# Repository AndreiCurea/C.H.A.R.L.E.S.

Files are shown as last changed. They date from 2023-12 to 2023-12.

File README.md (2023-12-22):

# C.H.A.R.L.E.S.
Combustion Hazzard Autonomous Robot for Localization and Environmental Scanning

A hobby project of mine that involves building up an exploration robot from scratch, using different types of technologies. The purpose of this project is to monitor VOCs and other harmful gases in office/industrial buildings, while also creating a map of the surroundings to plot the acquired data on it.

I desired it to have LiDAR, ROS implementation, main computer board and high modularity when it comes to the electrical/mechanical parts.

It has custom PCBs, custom 3D parts, and code for the microcontrollers and the main computer.

Currently, the project only works remote controlled, as I've yet to develop the automation part of the code.

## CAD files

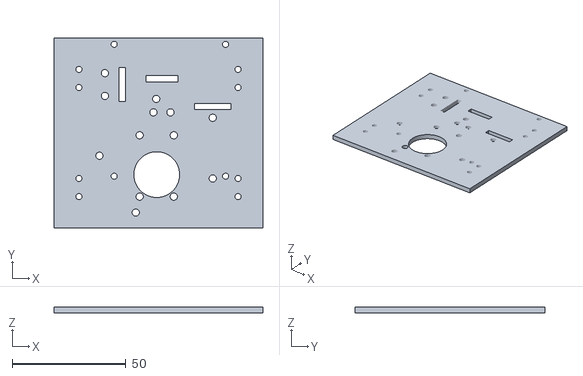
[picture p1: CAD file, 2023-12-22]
3D Designs/Assembly Bottom Layer v21.stl
91.9 x 83.6 x 2.50

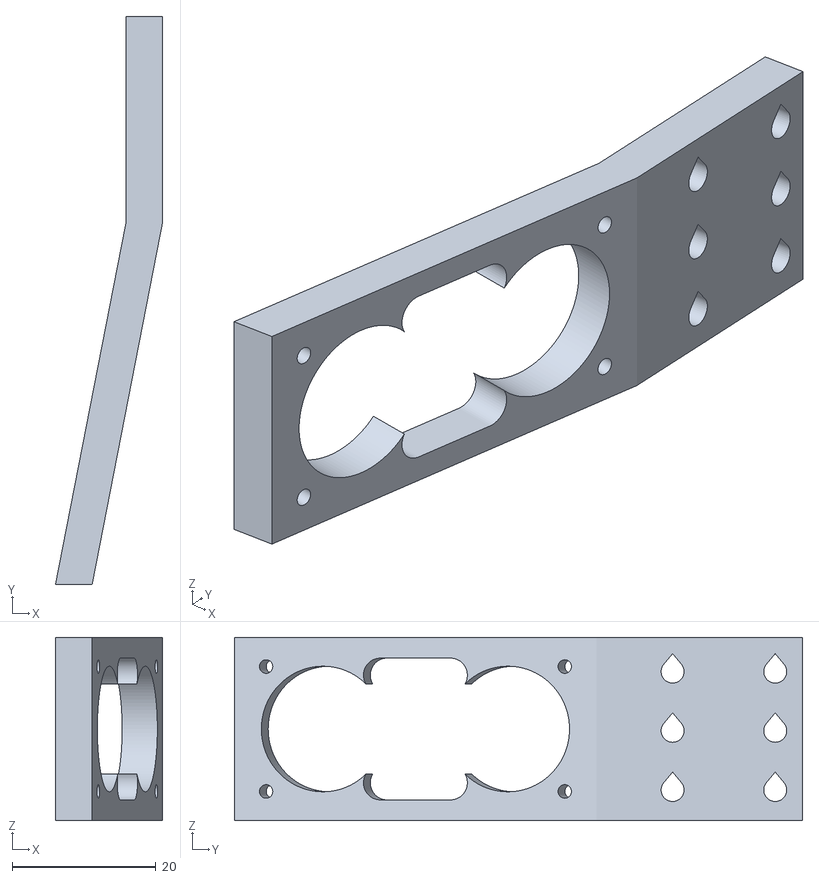
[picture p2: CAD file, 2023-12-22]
3D Designs/Aripa_Dreapta.stl
14.9 x 79.2 x 25.5

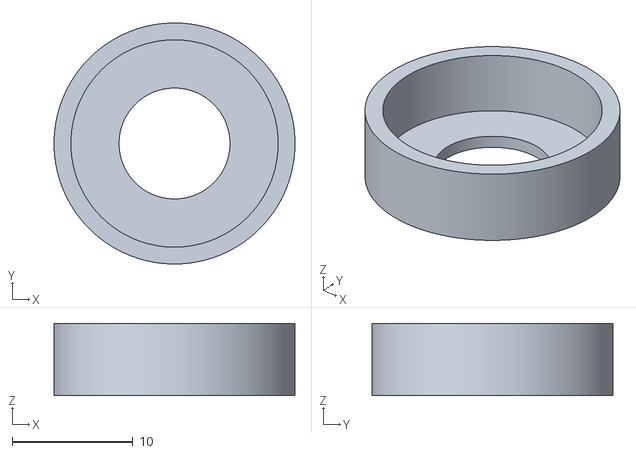
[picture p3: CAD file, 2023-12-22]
3D Designs/Test insert Motor.stl
20.0 x 20.0 x 6.00

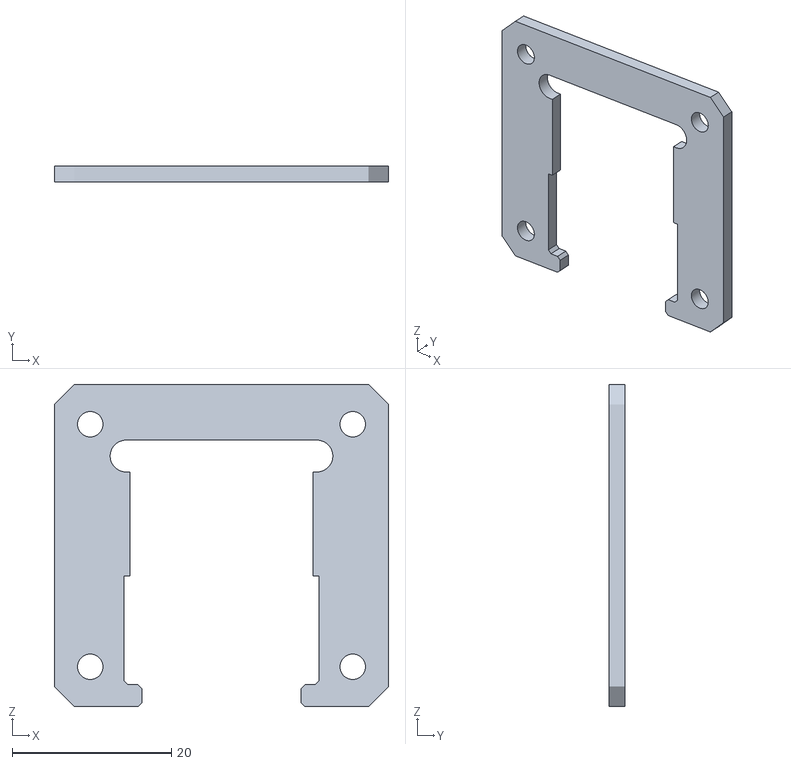
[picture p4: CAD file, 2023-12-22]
3D Designs/Capac_Battery_Level.stl
42.0 x 2.00 x 40.5

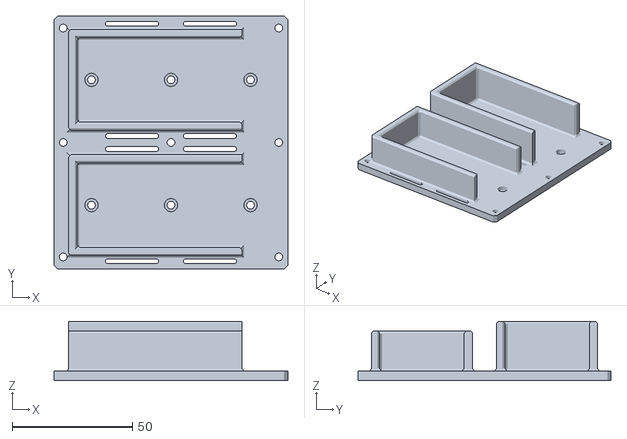
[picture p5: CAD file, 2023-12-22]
3D Designs/Suport_Baterii.stl
97.0 x 105.0 x 24.5

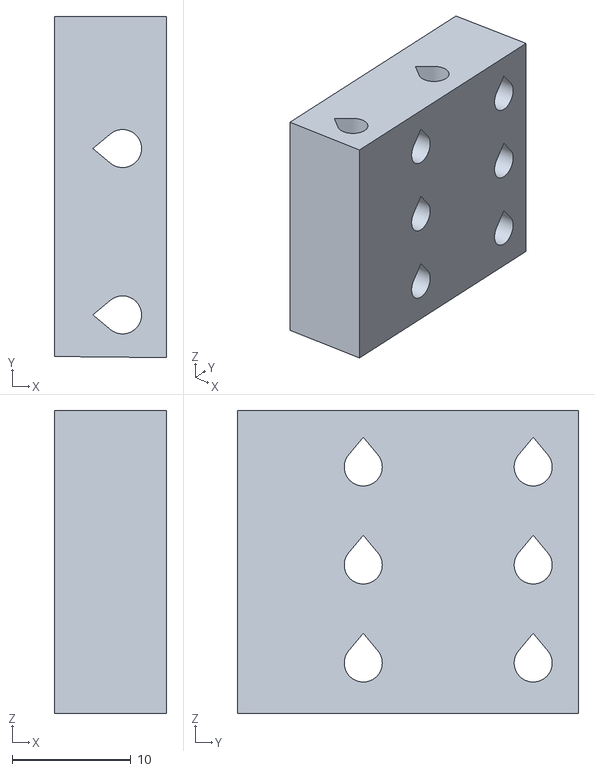
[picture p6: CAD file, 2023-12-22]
3D Designs/Bloc_Suport_Aripa_Dreapta.stl
9.44 x 28.7 x 25.5

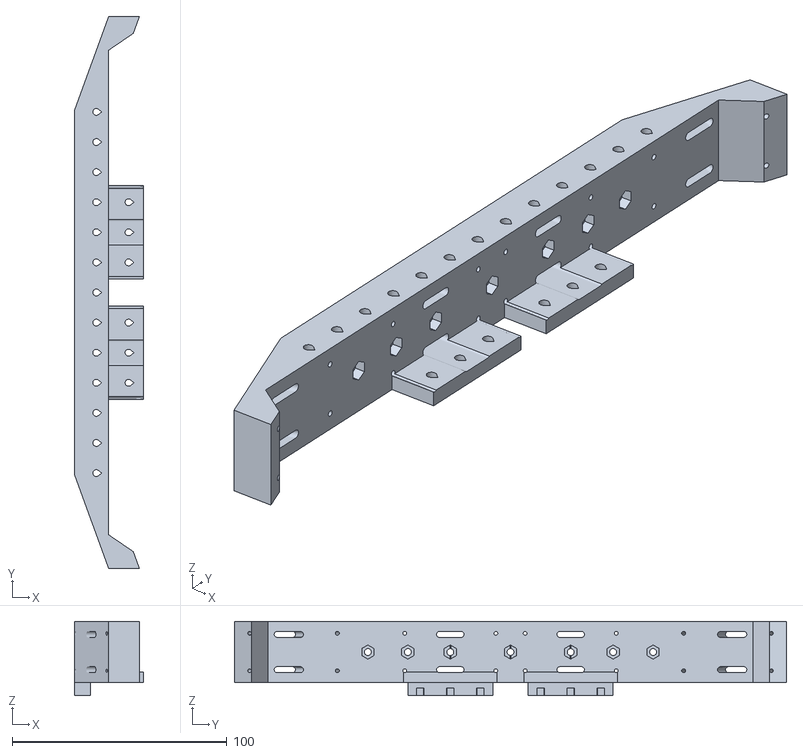
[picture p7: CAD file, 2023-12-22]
3D Designs/HC_SR04_Adapter.stl
32.0 x 256.8 x 34.5

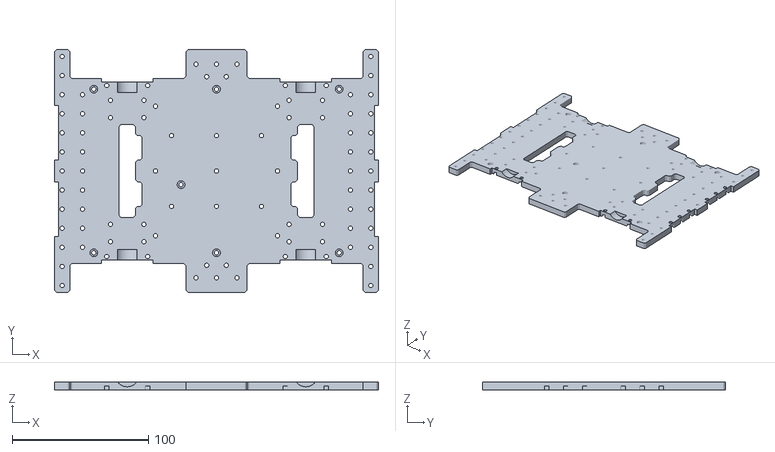
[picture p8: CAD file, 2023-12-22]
3D Designs/Bottom Layer 1.stl
237.7 x 178.0 x 6.00

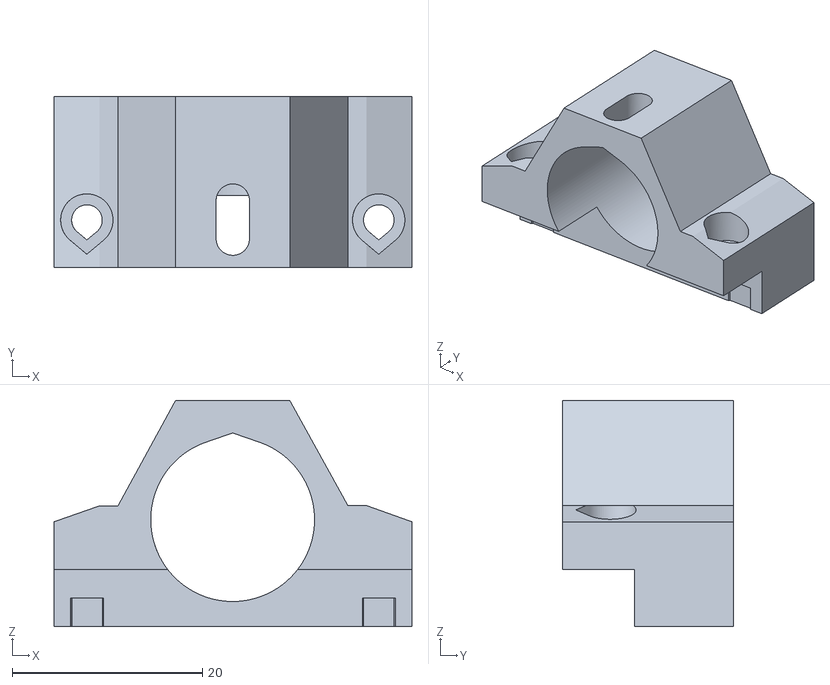
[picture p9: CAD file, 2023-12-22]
3D Designs/Suport_Rulment_Roata.stl
37.6 x 18.0 x 23.7

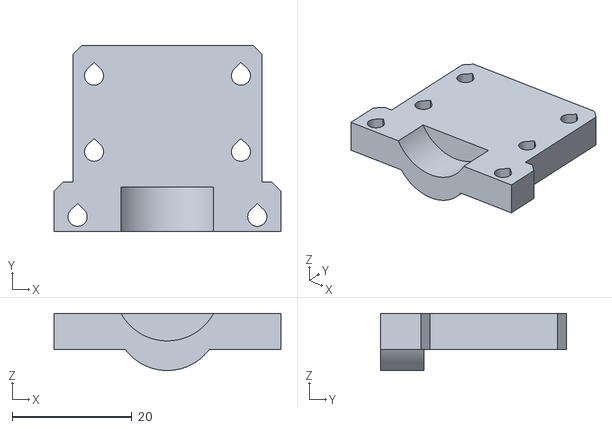
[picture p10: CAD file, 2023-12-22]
3D Designs/Inaltator_Roti.stl
37.9 x 31.1 x 9.52

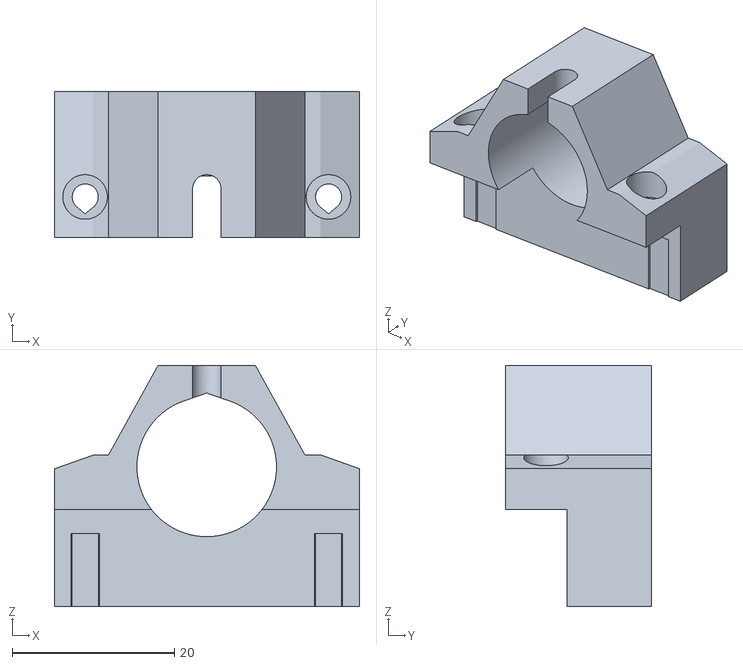
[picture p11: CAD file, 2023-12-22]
3D Designs/Suport_Rulment_Roata_plusInaltator.stl
37.6 x 18.0 x 29.7

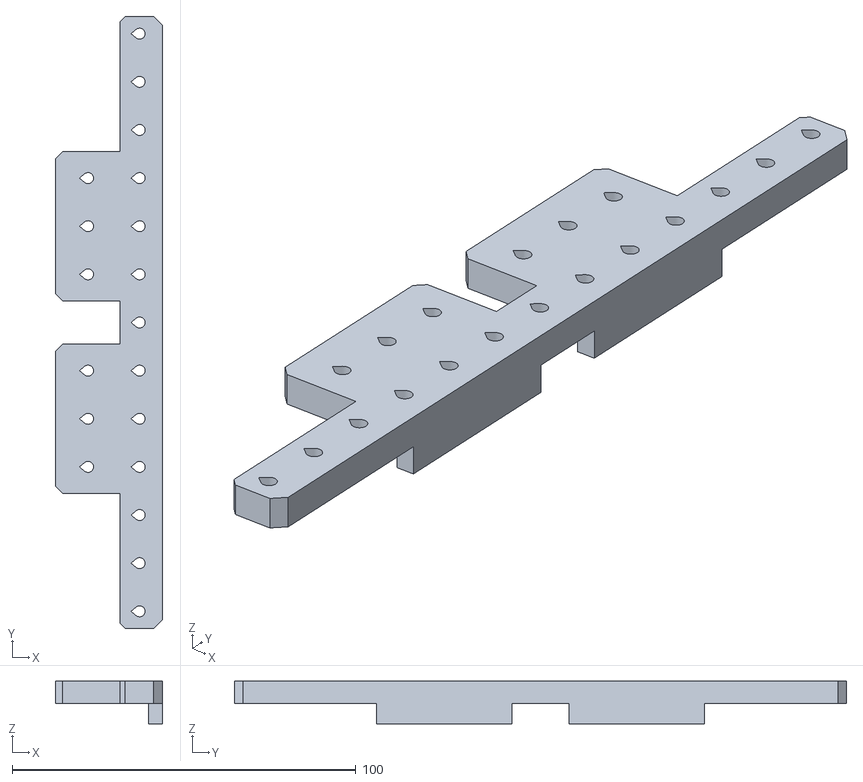
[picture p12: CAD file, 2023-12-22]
3D Designs/Base_Support_Ultrasonic.stl
31.0 x 178.0 x 12.5

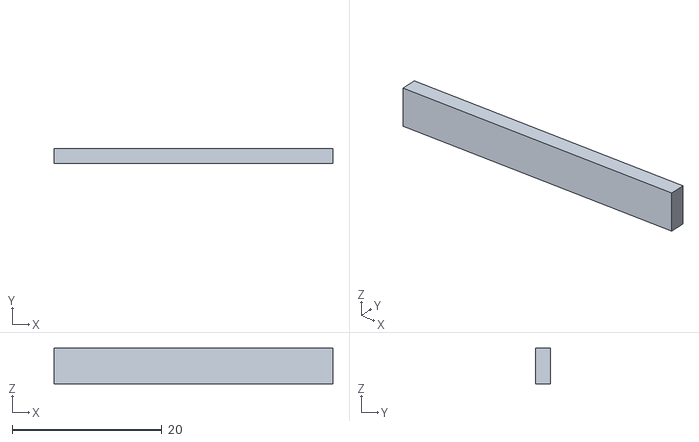
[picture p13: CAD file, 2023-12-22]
3D Designs/test insert MotM.stl
37.2 x 2.00 x 4.80

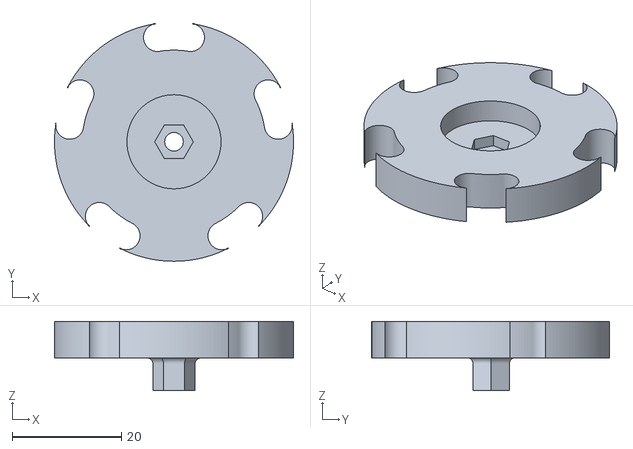
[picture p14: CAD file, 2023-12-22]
3D Designs/Suport_Roata.stl
43.7 x 43.4 x 12.7

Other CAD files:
3D Designs/Bottom Layer 1_Holes.stl
3D Designs/Aripa_Stanga.stl
3D Designs/Bloc_Suport_Aripa_Stanga.stl
3D Designs/Suport Motor.stl
3D Designs/Batt_ Conn_Dreapta.stl
3D Designs/Batt_ Conn_Stanga.stl
3D Designs/Clips_Cuplaj_Mecanic.stl
3D Designs/Front_Support_Ultrasonic.stl
3D Designs/Middle_Layer_2.stl
3D Designs/Separator Rulment.stl
3D Designs/Separator_Rulment.stl
3D Designs/Suport Separator Rulment.stl
3D Designs/Suport_Battery_Level.stl
3D Designs/TOP_Layer_3.stl
3D Designs/Test_HCSR04.stl
3D Designs/Test_Hole_Mot_Mount.stl
3D Designs/Test_Ins_Mot_Mount.stl
3D Designs/Ziptie_Holder.stl
3D Designs/test_Gauri.stl

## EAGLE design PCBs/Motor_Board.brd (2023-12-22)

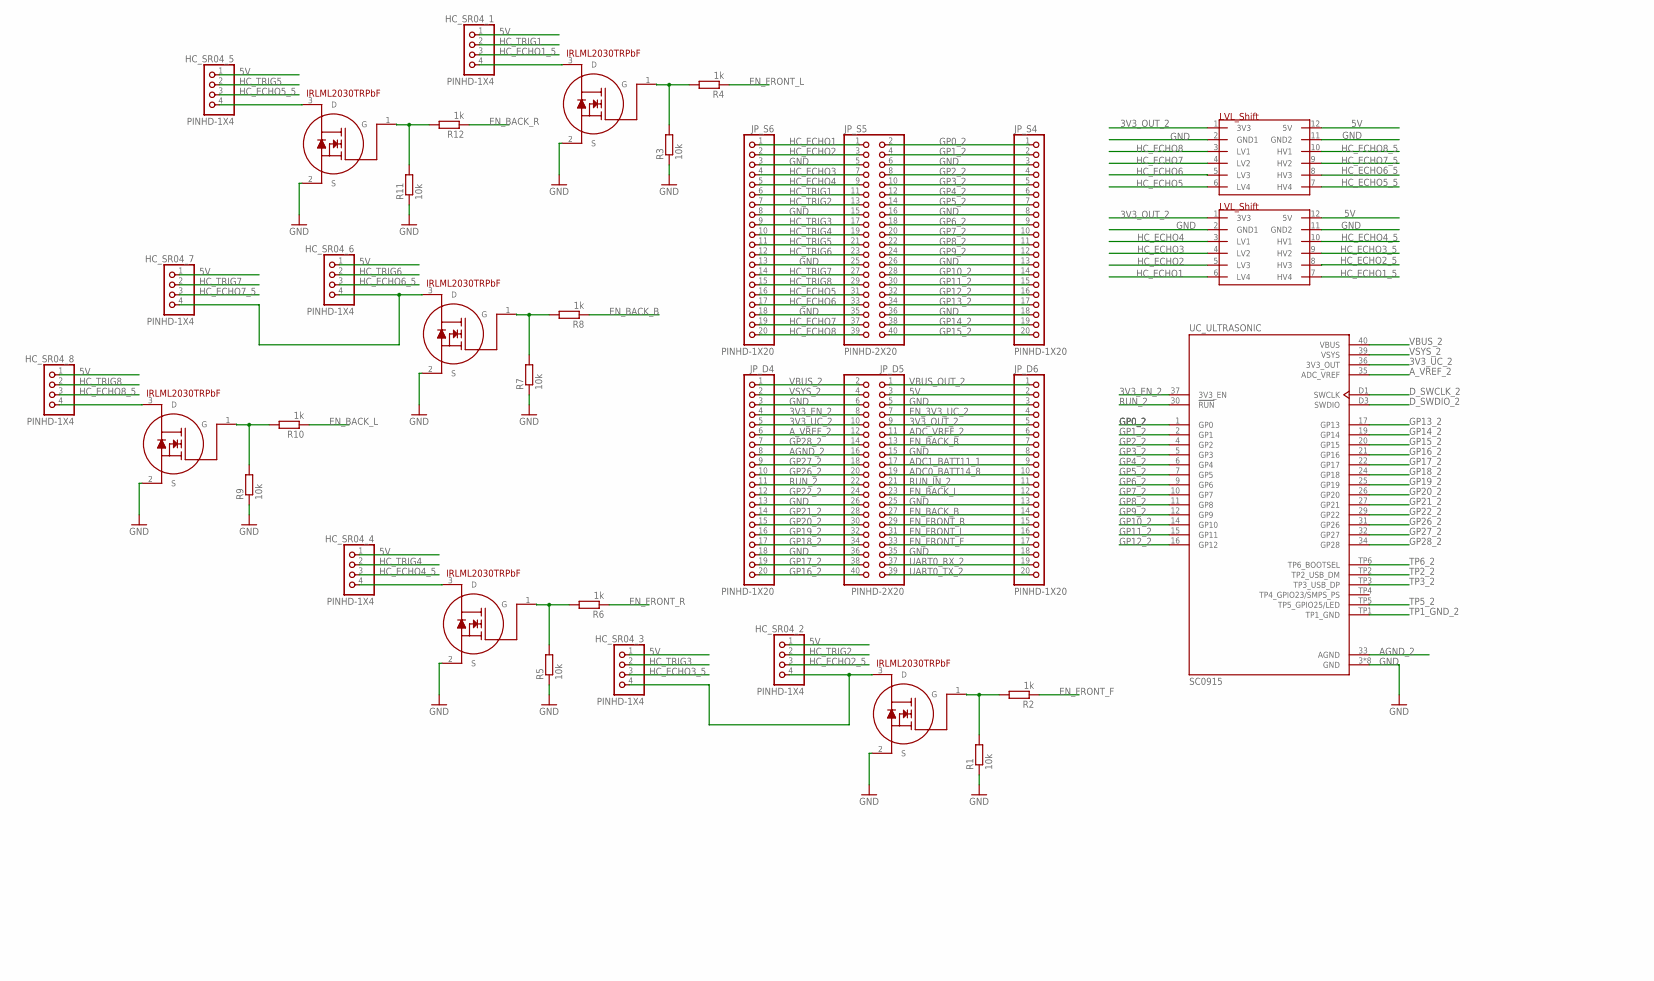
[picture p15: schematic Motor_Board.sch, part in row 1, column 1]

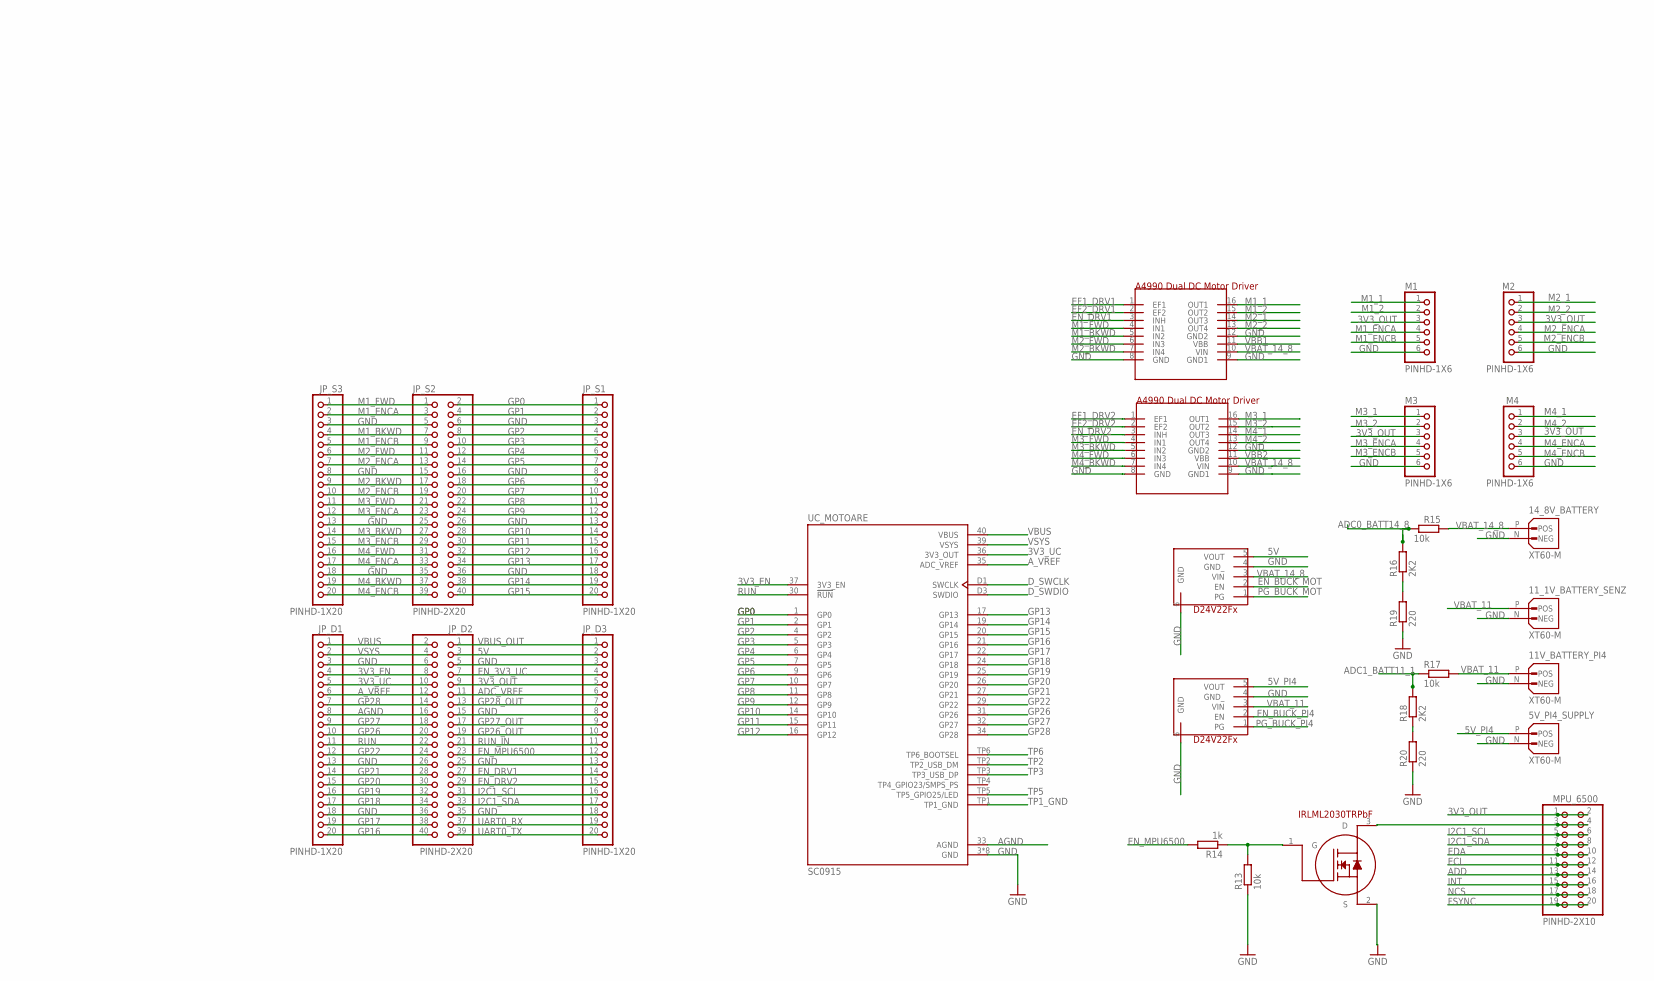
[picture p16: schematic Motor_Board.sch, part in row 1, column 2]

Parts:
5V_PI4_SUPPLY, 11V_BATTERY_PI4, 11_1V_BATTERY_SENZ, 14_8V_BATTERY: XT60-M; AMASS_XT60-M
BUCK_5V, BUCK_5V1: POLOLU_BUCK_CONVERTER; POLOLU_BUCK_FOOTPRINT
DRV1, DRV2: A4990_DUAL; A4990_FOOTPRINT
HC_SR04_1, HC_SR04_2, HC_SR04_3, HC_SR04_4, HC_SR04_5, HC_SR04_6, HC_SR04_7, HC_SR04_8: PINHD-1X4; 1X04
JP_D1, JP_D3, JP_D4, JP_D6: PINHD-1X20; 1X20
JP_D2, JP_D5: PINHD-2X20; 2X20
JP_S1, JP_S3, JP_S4, JP_S6: PINHD-1X20; 1X20
JP_S2, JP_S5: PINHD-2X20; 2X20
M1, M2, M3, M4: PINHD-1X6; 1X06
MPU_6500: PINHD-2X10; 2X10
R1, R3, R5, R7, R9, R11, R13, R15, R17: 10k; R0805
R2, R4, R6, R8, R10, R12, R14: 1k; R0805
R16, R18: 2K2; R0805
R19, R20: 220; R0805
U$1, U$2: 4_CH_BIDIRECTIONAL_LVL_SHIFTER; LVL_SHIFT_FOOTPRINT
U$8, U$9, U$10, U$11, U$12, U$13, U$14: IRLML2030TRBRBF_NMOS; IRLML2030TRPBF_FOOTPRINT
UC_MOTOARE: SC0915; MODULE_SC0915
UC_ULTRASONIC: SC0915; MODULE_SC0915

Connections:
3V3_EN: JP_D1.4, JP_D2.8, UC_MOTOARE.37 (3V3_EN)
3V3_EN_2: JP_D4.4, JP_D5.8, UC_ULTRASONIC.37 (3V3_EN)
3V3_OUT: JP_D2.9, JP_D3.5, M1.3, M2.3, M3.3, M4.3, MPU_6500.1, MPU_6500.2
3V3_OUT_2: JP_D5.9, JP_D6.5, U$1.1 (3V3), U$2.1 (3V3)
3V3_UC: JP_D1.5, JP_D2.10, UC_MOTOARE.36 (3V3_OUT)
3V3_UC_2: JP_D4.5, JP_D5.10, UC_ULTRASONIC.36 (3V3_OUT)
5V: BUCK_5V.5 (VOUT), HC_SR04_1.1, HC_SR04_2.1, HC_SR04_3.1, HC_SR04_4.1, HC_SR04_5.1, HC_SR04_6.1, HC_SR04_7.1, HC_SR04_8.1, JP_D2.3, JP_D3.2, JP_D5.3, JP_D6.2, U$1.12 (5V), U$2.12 (5V)
5V_PI4: 5V_PI4_SUPPLY.P (POS), BUCK_5V1.5 (VOUT)
ADC0_BATT14_8: JP_D5.19, JP_D6.10, R15.1, R16.2
ADC1_BATT11_1: JP_D5.17, JP_D6.9, R17.1, R18.2
ADC_VREF: JP_D2.11, JP_D3.6
ADC_VREF_2: JP_D5.11, JP_D6.6
ADD: MPU_6500.13, MPU_6500.14
AGND: JP_D1.8, JP_D2.16, UC_MOTOARE.33 (AGND)
AGND_2: JP_D4.8, JP_D5.16, UC_ULTRASONIC.33 (AGND)
A_VREF: JP_D1.6, JP_D2.12, UC_MOTOARE.35 (ADC_VREF)
A_VREF_2: JP_D4.6, JP_D5.12, UC_ULTRASONIC.35 (ADC_VREF)
D_SWCLK: UC_MOTOARE.D1 (SWCLK)
D_SWCLK_2: UC_ULTRASONIC.D1 (SWCLK)
D_SWDIO: UC_MOTOARE.D3 (SWDIO)
D_SWDIO_2: UC_ULTRASONIC.D3 (SWDIO)
ECL: MPU_6500.11, MPU_6500.12
EDA: MPU_6500.9, MPU_6500.10
EF1_DRV1: DRV1.1 (EF1)
EF1_DRV2: DRV2.1 (EF1)
EF2_DRV1: DRV1.2 (EF2)
EF2_DRV2: DRV2.2 (EF2)
EN_3V3_UC: JP_D2.7, JP_D3.4
EN_3V3_UC_2: JP_D5.7, JP_D6.4
EN_BACK_B: JP_D5.27, JP_D6.14, R8.1
EN_BACK_L: JP_D5.23, JP_D6.12, R10.1
EN_BACK_R: JP_D5.13, JP_D6.7, R12.1
EN_BUCK_MOT: BUCK_5V.2 (EN)
EN_BUCK_PI4: BUCK_5V1.2 (EN)
EN_DRV1: DRV1.3 (INH), JP_D2.27, JP_D3.14
EN_DRV2: DRV2.3 (INH), JP_D2.29, JP_D3.15
EN_FRONT_F: JP_D5.33, JP_D6.17, R2.1
EN_FRONT_L: JP_D5.31, JP_D6.16, R4.1
EN_FRONT_R: JP_D5.29, JP_D6.15, R6.1
EN_MPU6500: JP_D2.23, JP_D3.12, R14.2
FSYNC: MPU_6500.19, MPU_6500.20
GND: 5V_PI4_SUPPLY.N (NEG), 11V_BATTERY_PI4.N (NEG), 11_1V_BATTERY_SENZ.N (NEG), 14_8V_BATTERY.N (NEG), BUCK_5V.4 (GND_), BUCK_5V.6 (GND), BUCK_5V1.4 (GND_), BUCK_5V1.6 (GND), DRV1.8 (GND), DRV1.9 (GND1), DRV1.12 (GND2), DRV2.8 (GND), DRV2.9 (GND1), DRV2.12 (GND2), JP_D1.3, JP_D1.13, JP_D1.18, JP_D2.5, JP_D2.6, JP_D2.15, JP_D2.25, JP_D2.26, JP_D2.35, JP_D2.36, JP_D3.3, JP_D3.8, JP_D3.13, JP_D3.18, JP_D4.3, JP_D4.13, JP_D4.18, JP_D5.5, JP_D5.6, JP_D5.15, JP_D5.25, JP_D5.26, JP_D5.35, JP_D5.36, JP_D6.3, JP_D6.8, JP_D6.13, JP_D6.18, JP_S1.3, JP_S1.8, JP_S1.13, JP_S1.18, JP_S2.5, JP_S2.6, JP_S2.15, JP_S2.16, JP_S2.25, JP_S2.26, JP_S2.35, JP_S2.36, JP_S3.3, JP_S3.8, JP_S3.13, JP_S3.18, JP_S4.3, JP_S4.8, JP_S4.13, JP_S4.18, JP_S5.5, JP_S5.6, JP_S5.15, JP_S5.16, JP_S5.25, JP_S5.26, JP_S5.35, JP_S5.36, JP_S6.3, JP_S6.8, JP_S6.13, JP_S6.18, M1.6, M2.6, M3.6, M4.6, R1.1, R3.1, R5.1, R7.1, R9.1, R11.1, R13.1, R19.1, R20.1, U$1.2 (GND1), U$1.11 (GND2), U$2.2 (GND1), U$2.11 (GND2), U$8.2 (S), U$9.2 (S), U$10.2 (S), U$11.2 (S), U$12.2 (S), U$13.2 (S), U$14.2 (S), UC_MOTOARE.3 (GND), UC_MOTOARE.8 (GND), UC_MOTOARE.13 (GND), UC_MOTOARE.18 (GND), UC_MOTOARE.23 (GND), UC_MOTOARE.28 (GND), UC_MOTOARE.38 (GND), UC_MOTOARE.D2 (GND), UC_ULTRASONIC.3 (GND), UC_ULTRASONIC.8 (GND), UC_ULTRASONIC.13 (GND), UC_ULTRASONIC.18 (GND)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
GP0: JP_S1.1, JP_S2.2, UC_MOTOARE.1 (GP0)
GP0_2: JP_S4.1, JP_S5.2, UC_ULTRASONIC.1 (GP0)
GP1: JP_S1.2, JP_S2.4, UC_MOTOARE.2 (GP1)
GP1_2: JP_S4.2, JP_S5.4, UC_ULTRASONIC.2 (GP1)
GP2: JP_S1.4, JP_S2.8, UC_MOTOARE.4 (GP2)
GP2_2: JP_S4.4, JP_S5.8, UC_ULTRASONIC.4 (GP2)
GP3: JP_S1.5, JP_S2.10, UC_MOTOARE.5 (GP3)
GP3_2: JP_S4.5, JP_S5.10, UC_ULTRASONIC.5 (GP3)
GP4: JP_S1.6, JP_S2.12, UC_MOTOARE.6 (GP4)
GP4_2: JP_S4.6, JP_S5.12, UC_ULTRASONIC.6 (GP4)
GP5: JP_S1.7, JP_S2.14, UC_MOTOARE.7 (GP5)
GP5_2: JP_S4.7, JP_S5.14, UC_ULTRASONIC.7 (GP5)
GP6: JP_S1.9, JP_S2.18, UC_MOTOARE.9 (GP6)
GP6_2: JP_S4.9, JP_S5.18, UC_ULTRASONIC.9 (GP6)
GP7: JP_S1.10, JP_S2.20, UC_MOTOARE.10 (GP7)
GP7_2: JP_S4.10, JP_S5.20, UC_ULTRASONIC.10 (GP7)
GP8: JP_S1.11, JP_S2.22, UC_MOTOARE.11 (GP8)
GP8_2: JP_S4.11, JP_S5.22, UC_ULTRASONIC.11 (GP8)
GP9: JP_S1.12, JP_S2.24, UC_MOTOARE.12 (GP9)
GP9_2: JP_S4.12, JP_S5.24, UC_ULTRASONIC.12 (GP9)
GP10: JP_S1.14, JP_S2.28, UC_MOTOARE.14 (GP10)
GP10_2: JP_S4.14, JP_S5.28, UC_ULTRASONIC.14 (GP10)
GP11: JP_S1.15, JP_S2.30, UC_MOTOARE.15 (GP11)
GP11_2: JP_S4.15, JP_S5.30, UC_ULTRASONIC.15 (GP11)
GP12: JP_S1.16, JP_S2.32, UC_MOTOARE.16 (GP12)
GP12_2: JP_S4.16, JP_S5.32, UC_ULTRASONIC.16 (GP12)
GP13: JP_S1.17, JP_S2.34, UC_MOTOARE.17 (GP13)
GP13_2: JP_S4.17, JP_S5.34, UC_ULTRASONIC.17 (GP13)
GP14: JP_S1.19, JP_S2.38, UC_MOTOARE.19 (GP14)
GP14_2: JP_S4.19, JP_S5.38, UC_ULTRASONIC.19 (GP14)
GP15: JP_S1.20, JP_S2.40, UC_MOTOARE.20 (GP15)
GP15_2: JP_S4.20, JP_S5.40, UC_ULTRASONIC.20 (GP15)
GP16: JP_D1.20, JP_D2.40, UC_MOTOARE.21 (GP16)
GP16_2: JP_D4.20, JP_D5.40, UC_ULTRASONIC.21 (GP16)
GP17: JP_D1.19, JP_D2.38, UC_MOTOARE.22 (GP17)
GP17_2: JP_D4.19, JP_D5.38, UC_ULTRASONIC.22 (GP17)
GP18: JP_D1.17, JP_D2.34, UC_MOTOARE.24 (GP18)
GP18_2: JP_D4.17, JP_D5.34, UC_ULTRASONIC.24 (GP18)
GP19: JP_D1.16, JP_D2.32, UC_MOTOARE.25 (GP19)
GP19_2: JP_D4.16, JP_D5.32, UC_ULTRASONIC.25 (GP19)
GP20: JP_D1.15, JP_D2.30, UC_MOTOARE.26 (GP20)
GP20_2: JP_D4.15, JP_D5.30, UC_ULTRASONIC.26 (GP20)
GP21: JP_D1.14, JP_D2.28, UC_MOTOARE.27 (GP21)
GP21_2: JP_D4.14, JP_D5.28, UC_ULTRASONIC.27 (GP21)
GP22: JP_D1.12, JP_D2.24, UC_MOTOARE.29 (GP22)
GP22_2: JP_D4.12, JP_D5.24, UC_ULTRASONIC.29 (GP22)
GP26: JP_D1.10, JP_D2.20, UC_MOTOARE.31 (GP26)
GP26_2: JP_D4.10, JP_D5.20, UC_ULTRASONIC.31 (GP26)
GP26_OUT: JP_D2.19, JP_D3.10
GP27: JP_D1.9, JP_D2.18, UC_MOTOARE.32 (GP27)
GP27_2: JP_D4.9, JP_D5.18, UC_ULTRASONIC.32 (GP27)
GP27_OUT: JP_D2.17, JP_D3.9
GP28: JP_D1.7, JP_D2.14, UC_MOTOARE.34 (GP28)
GP28_2: JP_D4.7, JP_D5.14, UC_ULTRASONIC.34 (GP28)
GP28_OUT: JP_D2.13, JP_D3.7
HC_ECHO1: JP_S5.1, JP_S6.1, U$2.6 (LV4)
HC_ECHO1_5: HC_SR04_1.3, U$2.7 (HV4)
HC_ECHO2: JP_S5.3, JP_S6.2, U$2.5 (LV3)
HC_ECHO2_5: HC_SR04_2.3, U$2.8 (HV3)
HC_ECHO3: JP_S5.7, JP_S6.4, U$2.4 (LV2)
HC_ECHO3_5: HC_SR04_3.3, U$2.9 (HV2)
HC_ECHO4: JP_S5.9, JP_S6.5, U$2.3 (LV1)
HC_ECHO4_5: HC_SR04_4.3, U$2.10 (HV1)
HC_ECHO5: JP_S5.31, JP_S6.16, U$1.6 (LV4)
HC_ECHO5_5: HC_SR04_5.3, U$1.7 (HV4)
HC_ECHO6: JP_S5.33, JP_S6.17, U$1.5 (LV3)
HC_ECHO6_5: HC_SR04_6.3, U$1.8 (HV3)
HC_ECHO7: JP_S5.37, JP_S6.19, U$1.4 (LV2)
HC_ECHO7_5: HC_SR04_7.3, U$1.9 (HV2)
HC_ECHO8: JP_S5.39, JP_S6.20, U$1.3 (LV1)
HC_ECHO8_5: HC_SR04_8.3, U$1.10 (HV1)
HC_TRIG1: HC_SR04_1.2, JP_S5.11, JP_S6.6
HC_TRIG2: HC_SR04_2.2, JP_S5.13, JP_S6.7
HC_TRIG3: HC_SR04_3.2, JP_S5.17, JP_S6.9
HC_TRIG4: HC_SR04_4.2, JP_S5.19, JP_S6.10
HC_TRIG5: HC_SR04_5.2, JP_S5.21, JP_S6.11
HC_TRIG6: HC_SR04_6.2, JP_S5.23, JP_S6.12
HC_TRIG7: HC_SR04_7.2, JP_S5.27, JP_S6.14
HC_TRIG8: HC_SR04_8.2, JP_S5.29, JP_S6.15
I2C1_SCL: JP_D2.31, JP_D3.16, MPU_6500.5, MPU_6500.6
I2C1_SDA: JP_D2.33, JP_D3.17, MPU_6500.7, MPU_6500.8
INT: MPU_6500.15, MPU_6500.16
M1_1: DRV1.16 (OUT1), M1.1
M1_2: DRV1.15 (OUT2), M1.2
M1_BKWD: DRV1.5 (IN2), JP_S2.7, JP_S3.4
M1_ENCA: JP_S2.3, JP_S3.2, M1.4
M1_ENCB: JP_S2.9, JP_S3.5, M1.5
M1_FWD: DRV1.4 (IN1), JP_S2.1, JP_S3.1
M2_1: DRV1.14 (OUT3), M2.1
M2_2: DRV1.13 (OUT4), M2.2
M2_BKWD: DRV1.7 (IN4), JP_S2.17, JP_S3.9
M2_ENCA: JP_S2.13, JP_S3.7, M2.4
M2_ENCB: JP_S2.19, JP_S3.10, M2.5
M2_FWD: DRV1.6 (IN3), JP_S2.11, JP_S3.6
M3_1: DRV2.16 (OUT1), M3.1
M3_2: DRV2.15 (OUT2), M3.2
M3_BKWD: DRV2.5 (IN2), JP_S2.27, JP_S3.14
M3_ENCA: JP_S2.23, JP_S3.12, M3.4
M3_ENCB: JP_S2.29, JP_S3.15, M3.5
M3_FWD: DRV2.4 (IN1), JP_S2.21, JP_S3.11
M4_1: DRV2.14 (OUT3), M4.1
M4_2: DRV2.13 (OUT4), M4.2
M4_BKWD: DRV2.7 (IN4), JP_S2.37, JP_S3.19
M4_ENCA: JP_S2.33, JP_S3.17, M4.4
M4_ENCB: JP_S2.39, JP_S3.20, M4.5
M4_FWD: DRV2.6 (IN3), JP_S2.31, JP_S3.16
unnamed: HC_SR04_1.4, U$9.3 (D)
unnamed: R3.2, R4.2, U$9.1 (G)
unnamed: HC_SR04_2.4, HC_SR04_3.4, U$10.3 (D)
unnamed: R1.2, R2.2, U$10.1 (G)
unnamed: HC_SR04_4.4, U$11.3 (D)
unnamed: R5.2, R6.2, U$11.1 (G)
unnamed: HC_SR04_5.4, U$12.3 (D)
unnamed: R11.2, R12.2, U$12.1 (G)
unnamed: R7.2, R8.2, U$13.1 (G)
unnamed: HC_SR04_6.4, HC_SR04_7.4, U$13.3 (D)
unnamed: HC_SR04_8.4, U$14.3 (D)
unnamed: R9.2, R10.2, U$14.1 (G)
unnamed: MPU_6500.3, MPU_6500.4, U$8.3 (D)
unnamed: R13.2, R14.1, U$8.1 (G)
unnamed: R16.1, R19.2
unnamed: R18.1, R20.2
NCS: MPU_6500.17, MPU_6500.18
PG_BUCK_MOT: BUCK_5V.1 (PG)
PG_BUCK_PI4: BUCK_5V1.1 (PG)
RUN: JP_D1.11, JP_D2.22, UC_MOTOARE.30 (!RUN)
RUN_2: JP_D4.11, JP_D5.22, UC_ULTRASONIC.30 (!RUN)
RUN_IN: JP_D2.21, JP_D3.11
RUN_IN_2: JP_D5.21, JP_D6.11
TP1_GND: UC_MOTOARE.TP1 (TP1_GND)
TP1_GND_2: UC_ULTRASONIC.TP1 (TP1_GND)
TP2: UC_MOTOARE.TP2 (TP2_USB_DM)
TP2_2: UC_ULTRASONIC.TP2 (TP2_USB_DM)
TP3: UC_MOTOARE.TP3 (TP3_USB_DP)
TP3_2: UC_ULTRASONIC.TP3 (TP3_USB_DP)
TP5: UC_MOTOARE.TP5 (TP5_GPIO25/LED)
TP5_2: UC_ULTRASONIC.TP5 (TP5_GPIO25/LED)
TP6: UC_MOTOARE.TP6 (TP6_BOOTSEL)
TP6_2: UC_ULTRASONIC.TP6 (TP6_BOOTSEL)
UART0_RX: JP_D2.37, JP_D3.19
UART0_RX_2: JP_D5.37, JP_D6.19
UART0_TX: JP_D2.39, JP_D3.20
UART0_TX_2: JP_D5.39, JP_D6.20
VBAT_11: 11V_BATTERY_PI4.P (POS), 11_1V_BATTERY_SENZ.P (POS), BUCK_5V1.3 (VIN), R17.2
VBAT_14_8: 14_8V_BATTERY.P (POS), BUCK_5V.3 (VIN), DRV1.10 (VIN), DRV2.10 (VIN), R15.2
VBB1: DRV1.11 (VBB)
VBB2: DRV2.11 (VBB)
VBUS: JP_D1.1, JP_D2.2, UC_MOTOARE.40 (VBUS)
VBUS_2: JP_D4.1, JP_D5.2, UC_ULTRASONIC.40 (VBUS)
VBUS_OUT: JP_D2.1, JP_D3.1
VBUS_OUT_2: JP_D5.1, JP_D6.1
VSYS: JP_D1.2, JP_D2.4, UC_MOTOARE.39 (VSYS)
VSYS_2: JP_D4.2, JP_D5.4, UC_ULTRASONIC.39 (VSYS)

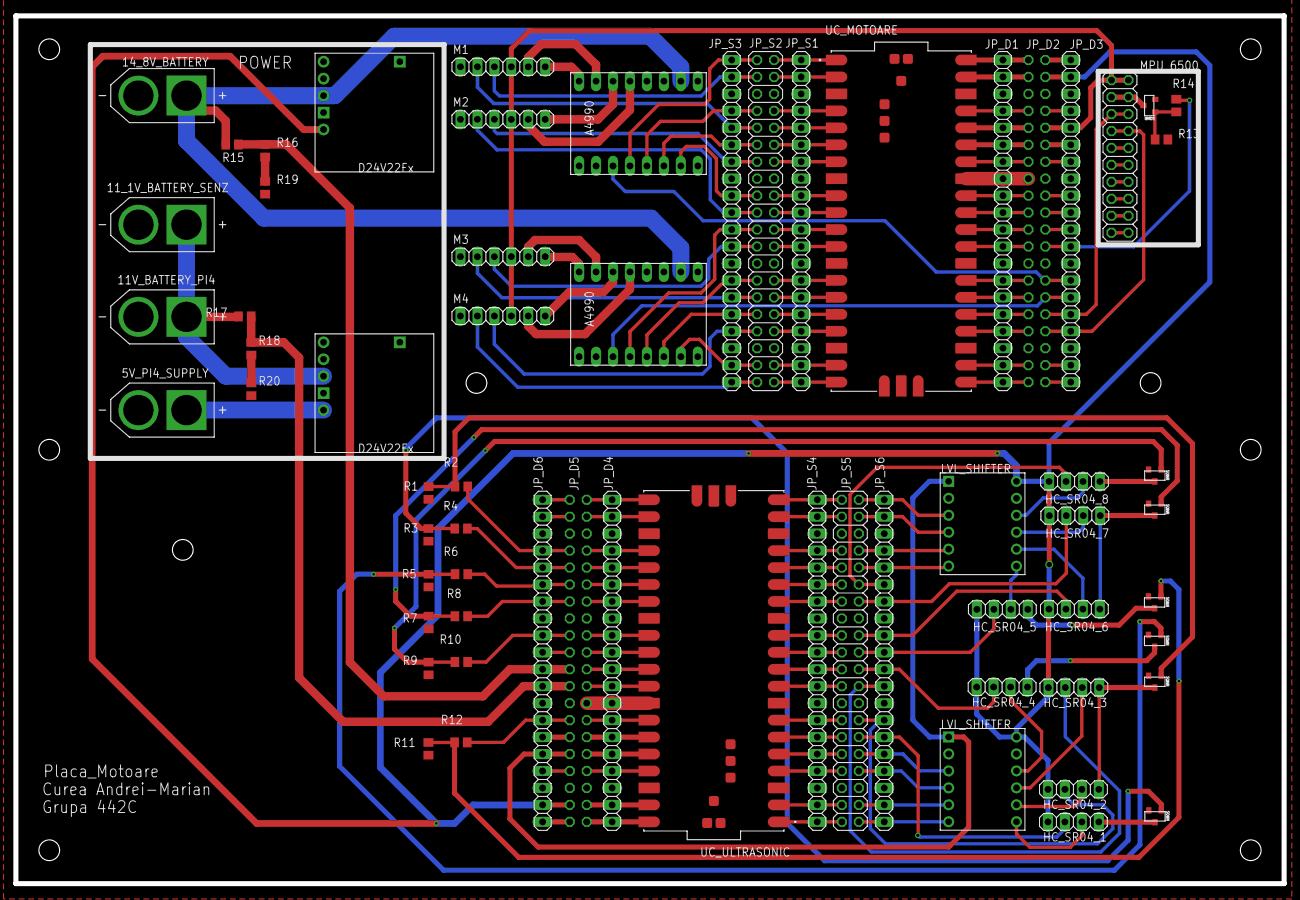
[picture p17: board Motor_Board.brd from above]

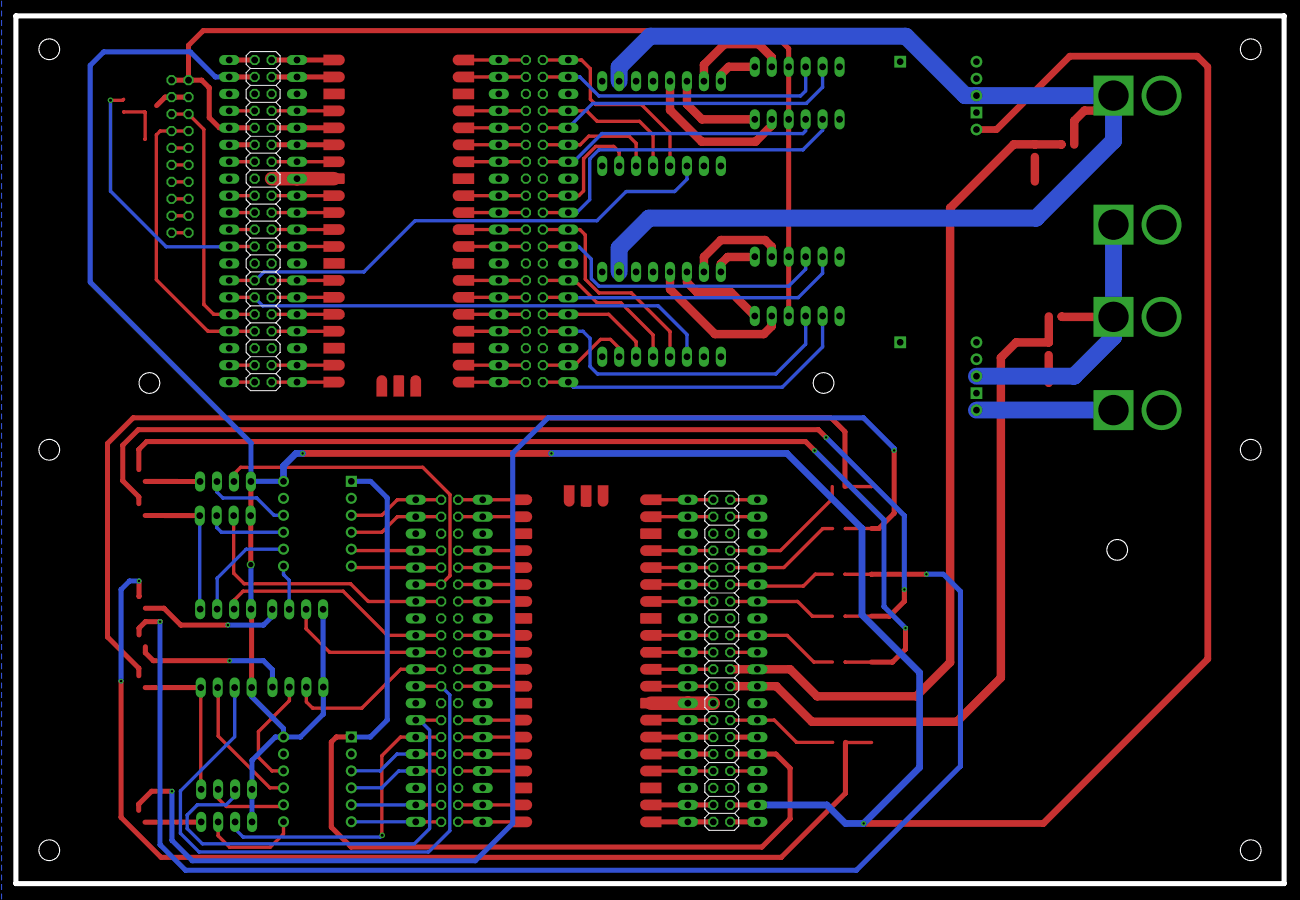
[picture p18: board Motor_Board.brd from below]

Board: 2 copper layers, 190.0 x 130.0 mm, 64 parts (2 on the bottom side), 171 nets.

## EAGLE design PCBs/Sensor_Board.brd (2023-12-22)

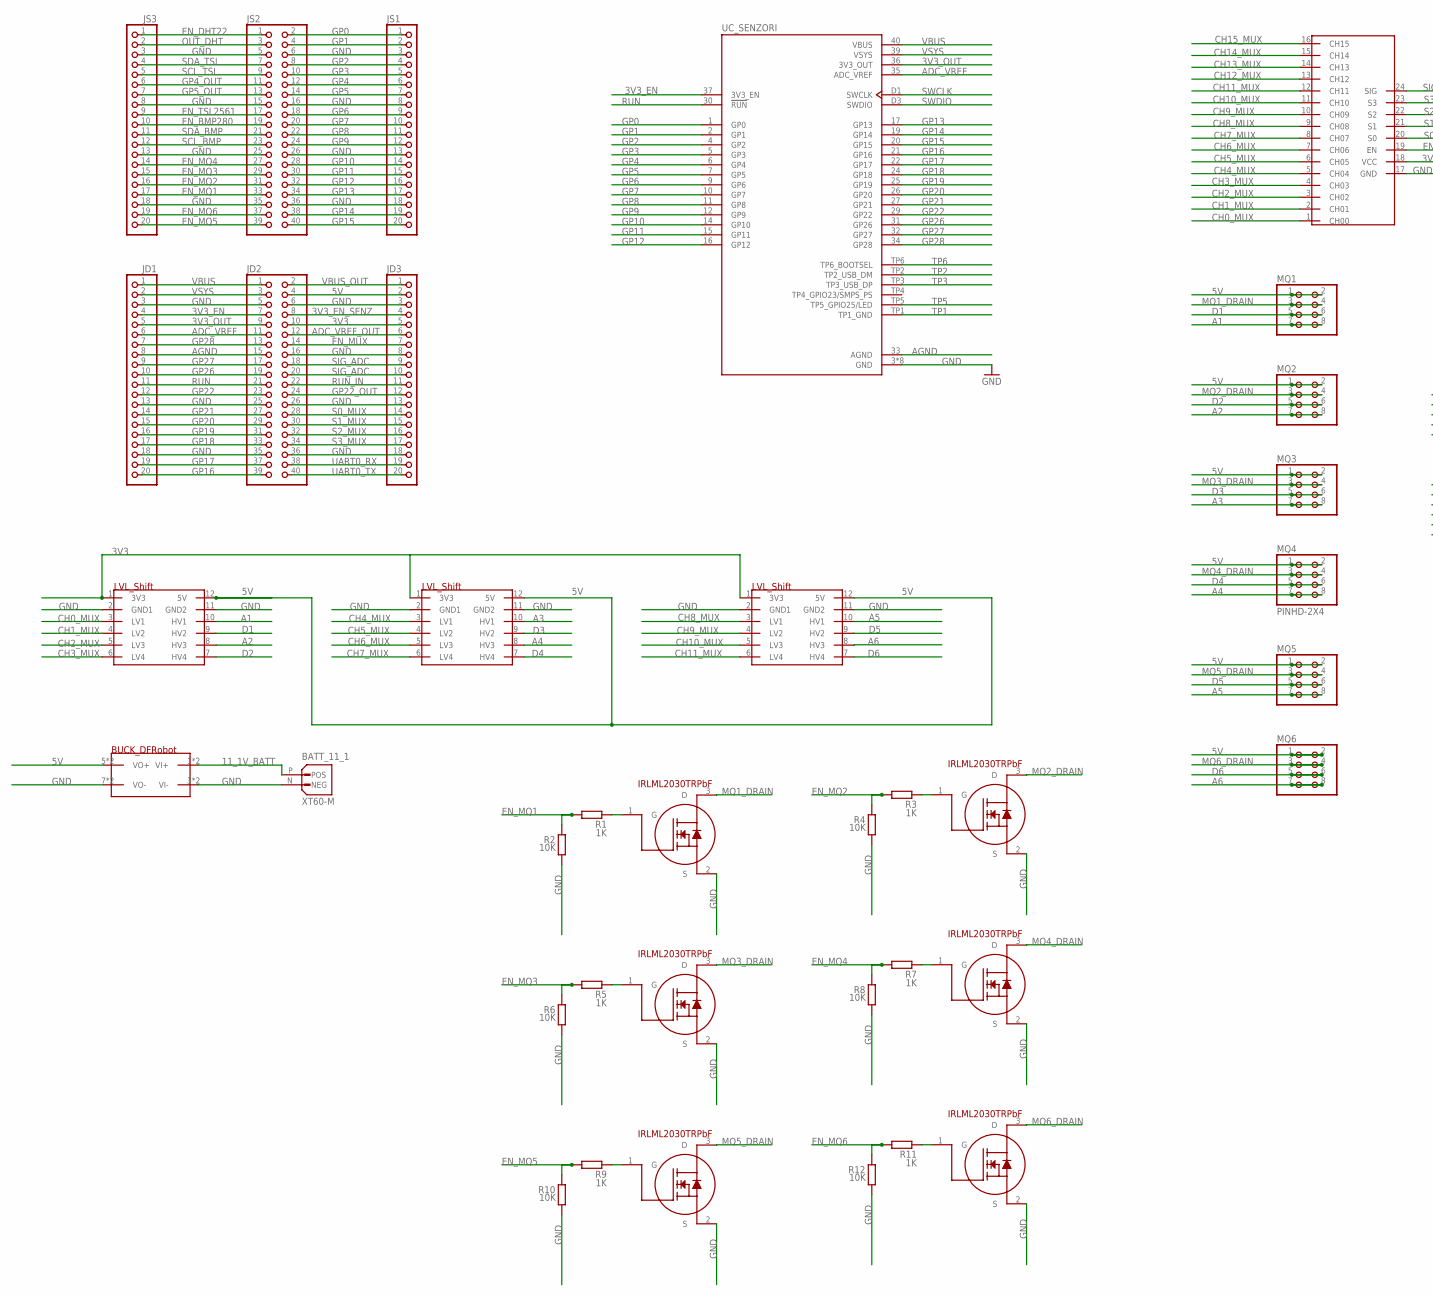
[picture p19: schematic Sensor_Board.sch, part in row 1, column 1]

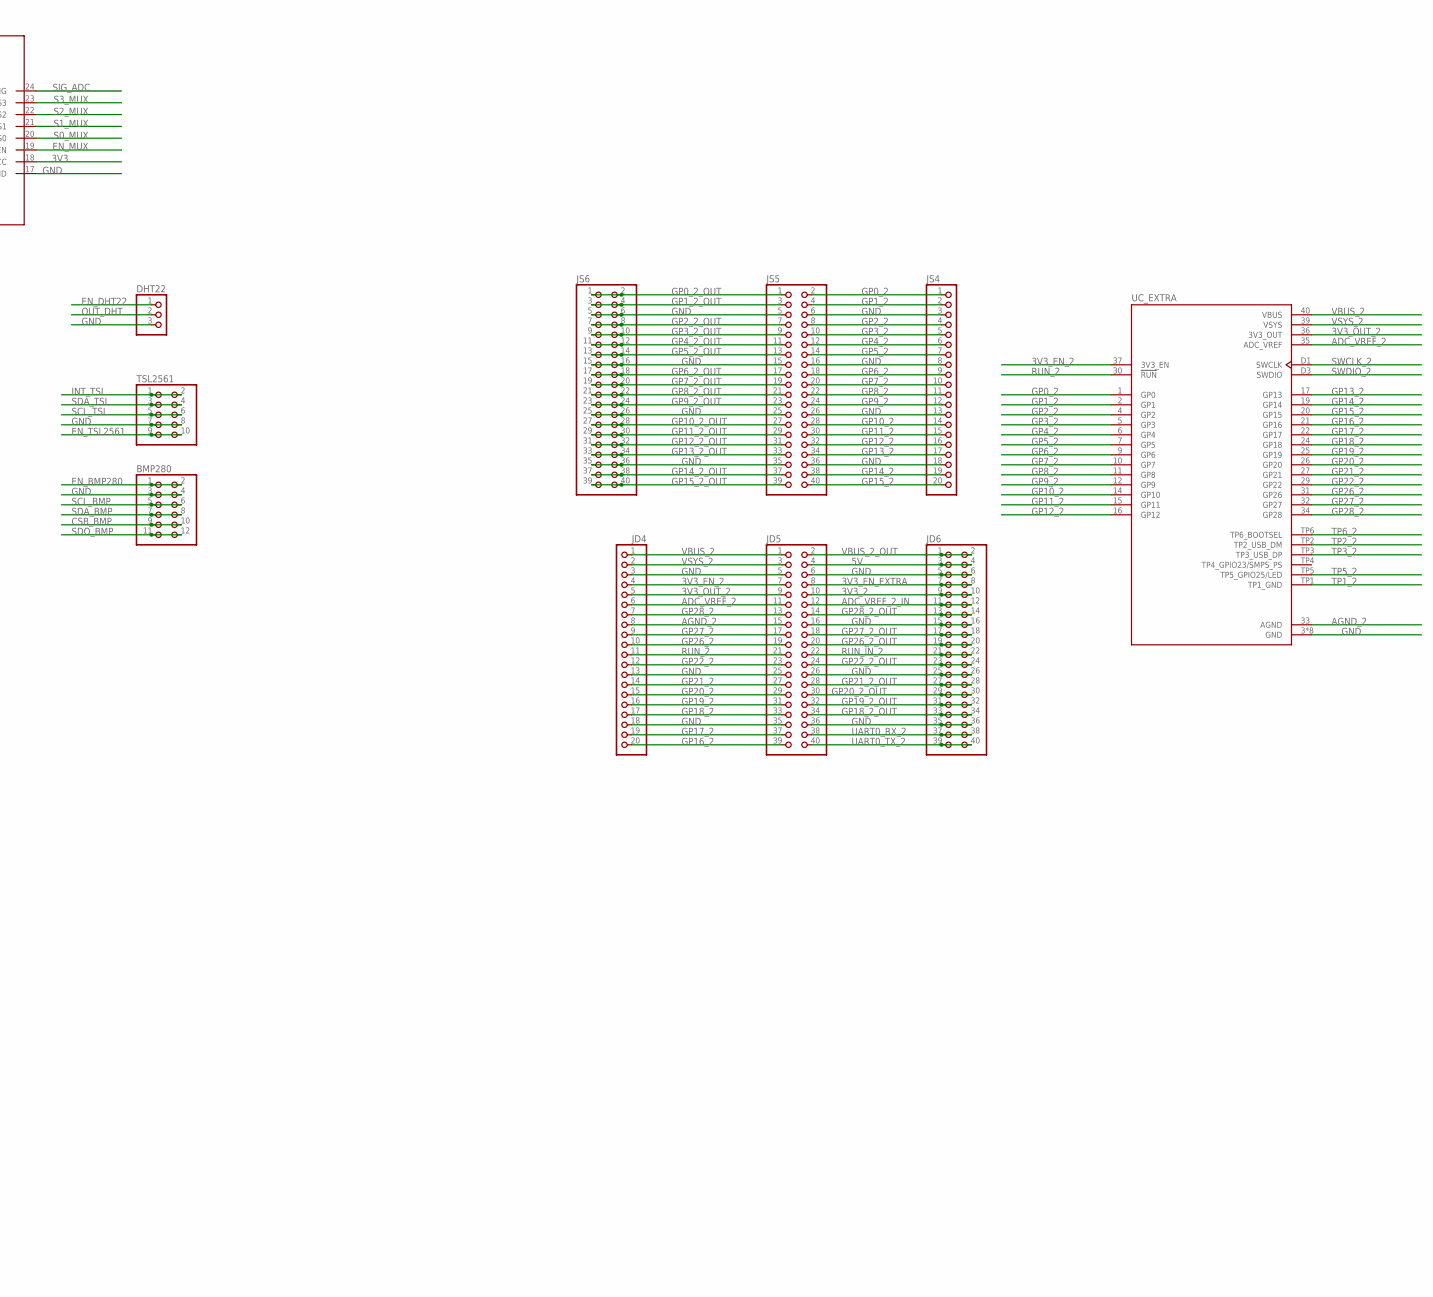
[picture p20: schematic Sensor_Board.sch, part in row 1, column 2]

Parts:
BATT_11_1: XT60-M; AMASS_XT60-M
BMP280: PINHD-2X6; 2X06
DHT22: PINHD-1X3; 1X03
JD1, JD3, JD4: PINHD-1X20; 1X20
JD2, JD5, JD6: PINHD-2X20; 2X20
JS1, JS3, JS4: PINHD-1X20; 1X20
JS2, JS5, JS6: PINHD-2X20; 2X20
MQ1, MQ2, MQ3, MQ4, MQ5, MQ6: PINHD-2X4; 2X04
MUX: CD74HC4067_MUX; 16_CH_MUX_FOOTPRINT
R1, R3, R5, R7, R9, R11: 1K; R0805
R2, R4, R6, R8, R10, R12: 10K; R0805
TSL2561: PINHD-2X5; 2X05
U$1, U$7, U$8, U$9, U$10, U$11: IRLML2030TRBRBF_NMOS; IRLML2030TRPBF_FOOTPRINT
U$2, U$3, U$4: 4_CH_BIDIRECTIONAL_LVL_SHIFTER; LVL_SHIFT_FOOTPRINT
U$5: DFROBOT_BUCK_CONVERTER; DFROBOT_BUCK_FOOTPRINT
UC_EXTRA: SC0915; MODULE_SC0915
UC_SENZORI: SC0915; MODULE_SC0915

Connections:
3V3: JD2.10, JD3.5, MUX.18 (VCC), U$2.1 (3V3), U$3.1 (3V3), U$4.1 (3V3)
3V3_2: JD5.10, JD6.9, JD6.10
3V3_EN: JD1.4, JD2.7, UC_SENZORI.37 (3V3_EN)
3V3_EN_2: JD4.4, JD5.7, UC_EXTRA.37 (3V3_EN)
3V3_EN_EXTRA: JD5.8, JD6.7, JD6.8
3V3_EN_SENZ: JD2.8, JD3.4
3V3_OUT: JD1.5, JD2.9, UC_SENZORI.36 (3V3_OUT)
3V3_OUT_2: JD4.5, JD5.9, UC_EXTRA.36 (3V3_OUT)
5V: JD2.4, JD3.2, JD5.4, JD6.3, JD6.4, MQ1.1, MQ1.2, MQ2.1, MQ2.2, MQ3.1, MQ3.2, MQ4.1, MQ4.2, MQ5.1, MQ5.2, MQ6.1, MQ6.2, U$2.12 (5V), U$3.12 (5V), U$4.12 (5V), U$5.5 (VO+), U$5.6 (VO+)
11_1V_BATT: BATT_11_1.P (POS), U$5.1 (VI+), U$5.2 (VI+)
A1: MQ1.7, MQ1.8, U$2.10 (HV1)
A2: MQ2.7, MQ2.8, U$2.8 (HV3)
A3: MQ3.7, MQ3.8, U$3.10 (HV1)
A4: MQ4.7, MQ4.8, U$3.8 (HV3)
A5: MQ5.7, MQ5.8, U$4.10 (HV1)
A6: MQ6.7, MQ6.8, U$4.8 (HV3)
ADC_VREF: JD1.6, JD2.11, UC_SENZORI.35 (ADC_VREF)
ADC_VREF_2: JD4.6, JD5.11, UC_EXTRA.35 (ADC_VREF)
ADC_VREF_2_IN: JD5.12, JD6.11, JD6.12
ADC_VREF_OUT: JD2.12, JD3.6
AGND: JD1.8, JD2.15, UC_SENZORI.33 (AGND)
AGND_2: JD4.8, JD5.15, UC_EXTRA.33 (AGND)
CH0_MUX: MUX.1 (CH00), U$2.3 (LV1)
CH1_MUX: MUX.2 (CH01), U$2.4 (LV2)
CH2_MUX: MUX.3 (CH02), U$2.5 (LV3)
CH3_MUX: MUX.4 (CH03), U$2.6 (LV4)
CH4_MUX: MUX.5 (CH04), U$3.3 (LV1)
CH5_MUX: MUX.6 (CH05), U$3.4 (LV2)
CH6_MUX: MUX.7 (CH06), U$3.5 (LV3)
CH7_MUX: MUX.8 (CH07), U$3.6 (LV4)
CH8_MUX: MUX.9 (CH08), U$4.3 (LV1)
CH9_MUX: MUX.10 (CH09), U$4.4 (LV2)
CH10_MUX: MUX.11 (CH10), U$4.5 (LV3)
CH11_MUX: MUX.12 (CH11), U$4.6 (LV4)
CH12_MUX: MUX.13 (CH12)
CH13_MUX: MUX.14 (CH13)
CH14_MUX: MUX.15 (CH14)
CH15_MUX: MUX.16 (CH15)
CSB_BMP: BMP280.9, BMP280.10
D1: MQ1.5, MQ1.6, U$2.9 (HV2)
D2: MQ2.5, MQ2.6, U$2.7 (HV4)
D3: MQ3.5, MQ3.6, U$3.9 (HV2)
D4: MQ4.5, MQ4.6, U$3.7 (HV4)
D5: MQ5.5, MQ5.6, U$4.9 (HV2)
D6: MQ6.5, MQ6.6, U$4.7 (HV4)
EN_BMP280: BMP280.1, BMP280.2, JS2.19, JS3.10
EN_DHT22: DHT22.1, JS2.1, JS3.1
EN_MQ1: JS2.33, JS3.17, R1.2, R2.2
EN_MQ2: JS2.31, JS3.16, R3.2, R4.2
EN_MQ3: JS2.29, JS3.15, R5.2, R6.2
EN_MQ4: JS2.27, JS3.14, R7.2, R8.2
EN_MQ5: JS2.39, JS3.20, R9.2, R10.2
EN_MQ6: JS2.37, JS3.19, R11.2, R12.2
EN_MUX: JD2.14, JD3.7, MUX.19 (EN)
EN_TSL2561: JS2.17, JS3.9, TSL2561.9, TSL2561.10
GND: BATT_11_1.N (NEG), BMP280.3, BMP280.4, DHT22.3, JD1.3, JD1.13, JD1.18, JD2.5, JD2.6, JD2.16, JD2.25, JD2.26, JD2.35, JD2.36, JD3.3, JD3.8, JD3.13, JD3.18, JD4.3, JD4.13, JD4.18, JD5.5, JD5.6, JD5.16, JD5.25, JD5.26, JD5.35, JD5.36, JD6.5, JD6.6, JD6.15, JD6.16, JD6.25, JD6.26, JD6.35, JD6.36, JS1.3, JS1.8, JS1.13, JS1.18, JS2.5, JS2.6, JS2.15, JS2.16, JS2.25, JS2.26, JS2.35, JS2.36, JS3.3, JS3.8, JS3.13, JS3.18, JS4.3, JS4.8, JS4.13, JS4.18, JS5.5, JS5.6, JS5.15, JS5.16, JS5.25, JS5.26, JS5.35, JS5.36, JS6.5, JS6.6, JS6.15, JS6.16, JS6.25, JS6.26, JS6.35, JS6.36, MUX.17 (GND), R2.1, R4.1, R6.1, R8.1, R10.1, R12.1, TSL2561.7, TSL2561.8, U$1.2 (S), U$2.2 (GND1), U$2.11 (GND2), U$3.2 (GND1), U$3.11 (GND2), U$4.2 (GND1), U$4.11 (GND2), U$5.3 (VI-), U$5.4 (VI-), U$5.7 (VO-), U$5.8 (VO-), U$7.2 (S), U$8.2 (S), U$9.2 (S), U$10.2 (S), U$11.2 (S), UC_EXTRA.3 (GND), UC_EXTRA.8 (GND), UC_EXTRA.13 (GND), UC_EXTRA.18 (GND), UC_EXTRA.23 (GND), UC_EXTRA.28 (GND), UC_EXTRA.38 (GND), UC_EXTRA.D2 (GND), UC_SENZORI.3 (GND), UC_SENZORI.8 (GND), UC_SENZORI.13 (GND), UC_SENZORI.18 (GND), UC_SENZORI.23 (GND)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
GP0: JS1.1, JS2.2, UC_SENZORI.1 (GP0)
GP0_2: JS4.1, JS5.2, UC_EXTRA.1 (GP0)
GP0_2_OUT: JS5.1, JS6.1, JS6.2
GP1: JS1.2, JS2.4, UC_SENZORI.2 (GP1)
GP1_2: JS4.2, JS5.4, UC_EXTRA.2 (GP1)
GP1_2_OUT: JS5.3, JS6.3, JS6.4
GP2: JS1.4, JS2.8, UC_SENZORI.4 (GP2)
GP2_2: JS4.4, JS5.8, UC_EXTRA.4 (GP2)
GP2_2_OUT: JS5.7, JS6.7, JS6.8
GP3: JS1.5, JS2.10, UC_SENZORI.5 (GP3)
GP3_2: JS4.5, JS5.10, UC_EXTRA.5 (GP3)
GP3_2_OUT: JS5.9, JS6.9, JS6.10
GP4: JS1.6, JS2.12, UC_SENZORI.6 (GP4)
GP4_2: JS4.6, JS5.12, UC_EXTRA.6 (GP4)
GP4_2_OUT: JS5.11, JS6.11, JS6.12
GP4_OUT: JS2.11, JS3.6
GP5: JS1.7, JS2.14, UC_SENZORI.7 (GP5)
GP5_2: JS4.7, JS5.14, UC_EXTRA.7 (GP5)
GP5_2_OUT: JS5.13, JS6.13, JS6.14
GP5_OUT: JS2.13, JS3.7
GP6: JS1.9, JS2.18, UC_SENZORI.9 (GP6)
GP6_2: JS4.9, JS5.18, UC_EXTRA.9 (GP6)
GP6_2_OUT: JS5.17, JS6.17, JS6.18
GP7: JS1.10, JS2.20, UC_SENZORI.10 (GP7)
GP7_2: JS4.10, JS5.20, UC_EXTRA.10 (GP7)
GP7_2_OUT: JS5.19, JS6.19, JS6.20
GP8: JS1.11, JS2.22, UC_SENZORI.11 (GP8)
GP8_2: JS4.11, JS5.22, UC_EXTRA.11 (GP8)
GP8_2_OUT: JS5.21, JS6.21, JS6.22
GP9: JS1.12, JS2.24, UC_SENZORI.12 (GP9)
GP9_2: JS4.12, JS5.24, UC_EXTRA.12 (GP9)
GP9_2_OUT: JS5.23, JS6.23, JS6.24
GP10: JS1.14, JS2.28, UC_SENZORI.14 (GP10)
GP10_2: JS4.14, JS5.28, UC_EXTRA.14 (GP10)
GP10_2_OUT: JS5.27, JS6.27, JS6.28
GP11: JS1.15, JS2.30, UC_SENZORI.15 (GP11)
GP11_2: JS4.15, JS5.30, UC_EXTRA.15 (GP11)
GP11_2_OUT: JS5.29, JS6.29, JS6.30
GP12: JS1.16, JS2.32, UC_SENZORI.16 (GP12)
GP12_2: JS4.16, JS5.32, UC_EXTRA.16 (GP12)
GP12_2_OUT: JS5.31, JS6.31, JS6.32
GP13: JS1.17, JS2.34, UC_SENZORI.17 (GP13)
GP13_2: JS4.17, JS5.34, UC_EXTRA.17 (GP13)
GP13_2_OUT: JS5.33, JS6.33, JS6.34
GP14: JS1.19, JS2.38, UC_SENZORI.19 (GP14)
GP14_2: JS4.19, JS5.38, UC_EXTRA.19 (GP14)
GP14_2_OUT: JS5.37, JS6.37, JS6.38
GP15: JS1.20, JS2.40, UC_SENZORI.20 (GP15)
GP15_2: JS4.20, JS5.40, UC_EXTRA.20 (GP15)
GP15_2_OUT: JS5.39, JS6.39, JS6.40
GP16: JD1.20, JD2.39, UC_SENZORI.21 (GP16)
GP16_2: JD4.20, JD5.39, UC_EXTRA.21 (GP16)
GP17: JD1.19, JD2.37, UC_SENZORI.22 (GP17)
GP17_2: JD4.19, JD5.37, UC_EXTRA.22 (GP17)
GP18: JD1.17, JD2.33, UC_SENZORI.24 (GP18)
GP18_2: JD4.17, JD5.33, UC_EXTRA.24 (GP18)
GP18_2_OUT: JD5.34, JD6.33, JD6.34
GP19: JD1.16, JD2.31, UC_SENZORI.25 (GP19)
GP19_2: JD4.16, JD5.31, UC_EXTRA.25 (GP19)
GP19_2_OUT: JD5.32, JD6.31, JD6.32
GP20: JD1.15, JD2.29, UC_SENZORI.26 (GP20)
GP20_2: JD4.15, JD5.29, UC_EXTRA.26 (GP20)
GP20_2_OUT: JD5.30, JD6.29, JD6.30
GP21: JD1.14, JD2.27, UC_SENZORI.27 (GP21)
GP21_2: JD4.14, JD5.27, UC_EXTRA.27 (GP21)
GP21_2_OUT: JD5.28, JD6.27, JD6.28
GP22: JD1.12, JD2.23, UC_SENZORI.29 (GP22)
GP22_2: JD4.12, JD5.23, UC_EXTRA.29 (GP22)
GP22_2_OUT: JD5.24, JD6.23, JD6.24
GP22_OUT: JD2.24, JD3.12
GP26: JD1.10, JD2.19, UC_SENZORI.31 (GP26)
GP26_2: JD4.10, JD5.19, UC_EXTRA.31 (GP26)
GP26_2_OUT: JD5.20, JD6.19, JD6.20
GP27: JD1.9, JD2.17, UC_SENZORI.32 (GP27)
GP27_2: JD4.9, JD5.17, UC_EXTRA.32 (GP27)
GP27_2_OUT: JD5.18, JD6.17, JD6.18
GP28: JD1.7, JD2.13, UC_SENZORI.34 (GP28)
GP28_2: JD4.7, JD5.13, UC_EXTRA.34 (GP28)
GP28_2_OUT: JD5.14, JD6.13, JD6.14
INT_TSL: TSL2561.1, TSL2561.2
MQ1_DRAIN: MQ1.3, MQ1.4, U$1.3 (D)
MQ2_DRAIN: MQ2.3, MQ2.4, U$7.3 (D)
MQ3_DRAIN: MQ3.3, MQ3.4, U$8.3 (D)
MQ4_DRAIN: MQ4.3, MQ4.4, U$9.3 (D)
MQ5_DRAIN: MQ5.3, MQ5.4, U$10.3 (D)
MQ6_DRAIN: MQ6.3, MQ6.4, U$11.3 (D)
unnamed: R1.1, U$1.1 (G)
unnamed: R3.1, U$7.1 (G)
unnamed: R5.1, U$8.1 (G)
unnamed: R7.1, U$9.1 (G)
unnamed: R9.1, U$10.1 (G)
unnamed: R11.1, U$11.1 (G)
OUT_DHT: DHT22.2, JS2.3, JS3.2
RUN: JD1.11, JD2.21, UC_SENZORI.30 (!RUN)
RUN_2: JD4.11, JD5.21, UC_EXTRA.30 (!RUN)
RUN_IN: JD2.22, JD3.11
RUN_IN_2: JD5.22, JD6.21, JD6.22
S0_MUX: JD2.28, JD3.14, MUX.20 (S0)
S1_MUX: JD2.30, JD3.15, MUX.21 (S1)
S2_MUX: JD2.32, JD3.16, MUX.22 (S2)
S3_MUX: JD2.34, JD3.17, MUX.23 (S3)
SCL_BMP: BMP280.5, BMP280.6, JS2.23, JS3.12
SCL_TSL: JS2.9, JS3.5, TSL2561.5, TSL2561.6
SDA_BMP: BMP280.7, BMP280.8, JS2.21, JS3.11
SDA_TSL: JS2.7, JS3.4, TSL2561.3, TSL2561.4
SDO_BMP: BMP280.11, BMP280.12
SIG_ADC: JD2.18, JD2.20, JD3.9, JD3.10, MUX.24 (SIG)
SWCLK: UC_SENZORI.D1 (SWCLK)
SWCLK_2: UC_EXTRA.D1 (SWCLK)
SWDIO: UC_SENZORI.D3 (SWDIO)
SWDIO_2: UC_EXTRA.D3 (SWDIO)
TP1: UC_SENZORI.TP1 (TP1_GND)
TP1_2: UC_EXTRA.TP1 (TP1_GND)
TP2: UC_SENZORI.TP2 (TP2_USB_DM)
TP2_2: UC_EXTRA.TP2 (TP2_USB_DM)
TP3: UC_SENZORI.TP3 (TP3_USB_DP)
TP3_2: UC_EXTRA.TP3 (TP3_USB_DP)
TP5: UC_SENZORI.TP5 (TP5_GPIO25/LED)
TP5_2: UC_EXTRA.TP5 (TP5_GPIO25/LED)
TP6: UC_SENZORI.TP6 (TP6_BOOTSEL)
TP6_2: UC_EXTRA.TP6 (TP6_BOOTSEL)
UART0_RX: JD2.38, JD3.19
UART0_RX_2: JD5.38, JD6.37, JD6.38
UART0_TX: JD2.40, JD3.20
UART0_TX_2: JD5.40, JD6.39, JD6.40
VBUS: JD1.1, JD2.1, UC_SENZORI.40 (VBUS)
VBUS_2: JD4.1, JD5.1, UC_EXTRA.40 (VBUS)
VBUS_2_OUT: JD5.2, JD6.1, JD6.2
VBUS_OUT: JD2.2, JD3.1
VSYS: JD1.2, JD2.3, UC_SENZORI.39 (VSYS)
VSYS_2: JD4.2, JD5.3, UC_EXTRA.39 (VSYS)

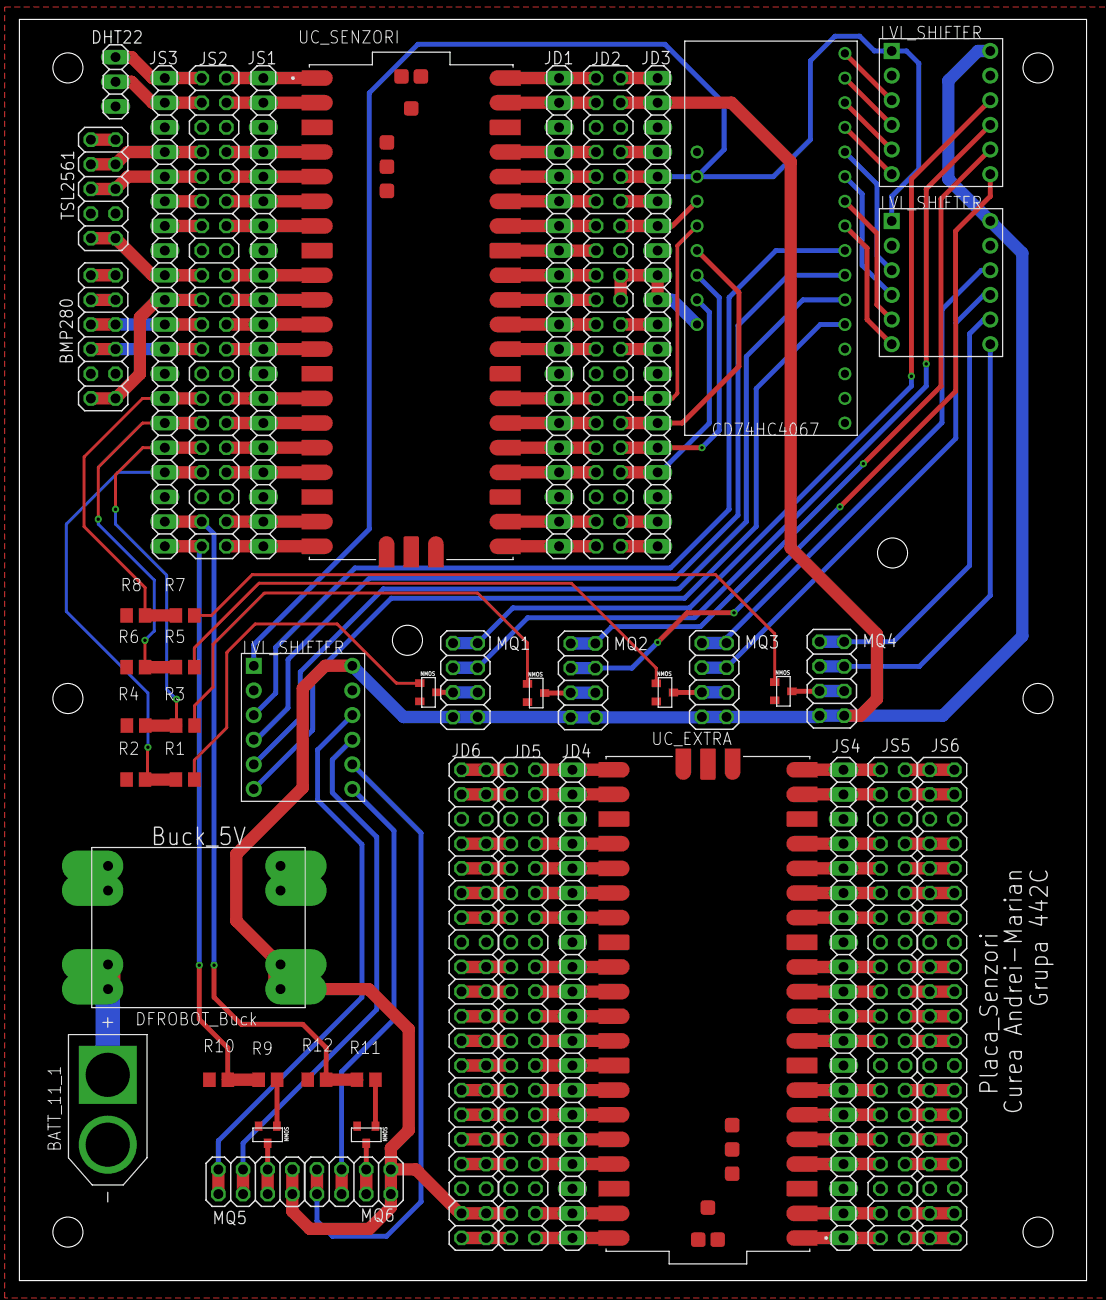
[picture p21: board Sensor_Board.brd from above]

Board: 2 copper layers, 110.0 x 130.0 mm, 47 parts (0 on the bottom side), 169 nets.

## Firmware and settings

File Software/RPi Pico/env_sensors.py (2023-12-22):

#This code is used for Environmental Sensors MicroController
#AKA pico_env_sensors
import select
import sys
import utime
from machine import Pin, I2C, ADC, time_pulse_us
import dht
import json

TSL2561_I2C_ADDR = 0x39

class TSL2561:
    def __init__(self, i2c):
        self.i2c = i2c
        self.i2c_addr = TSL2561_I2C_ADDR
        utime.sleep_ms(100)
        self.power_on()

    def power_on(self):
        self.i2c.writeto_mem(self.i2c_addr, 0x80, b'\x03') # Enable the device

    def power_off(self):
        self.i2c.writeto_mem(self.i2c_addr, 0x80, b'\x00') # Disable the device

    def read_lux(self):
        # Set the timing register to high gain and 402ms integration time
        self.i2c.writeto_mem(self.i2c_addr, 0x81, b'\x02')

        # Wait for the integration to complete
        utime.sleep_ms(402)

        # Read the sensor data
        data = self.i2c.readfrom_mem(self.i2c_addr, 0xAC, 2)

        # Combine the bytes into a 16-bit integer
        raw_lux = data[1] << 8 | data[0]

        # Extract the exponent and mantissa from the raw lux value
        exponent = (raw_lux & 0xF000) >> 12
        mantissa = raw_lux & 0x0FFF

        # Calculate the lux value based on the exponent and mantissa
        luminance = (2 ** exponent) * mantissa * 0.03125

        return luminance

class BMP280:
    def __init__(self, i2c, i2c_addr=0x76):
        self.i2c = i2c
        self.addr = i2c_addr
        self.dig_T1 = 0
        self.dig_T2 = 0
        self.dig_T3 = 0
        self.dig_P1 = 0
        self.dig_P2 = 0
        self.dig_P3 = 0
        self.dig_P4 = 0
        self.dig_P5 = 0
        self.dig_P6 = 0
        self.dig_P7 = 0
        self.dig_P8 = 0
        self.dig_P9 = 0
        self.read_calibration()
        self.configure()
        utime.sleep_ms(50)
        
    def configure(self):
        # Configure the ctrl_meas register (0xF4)
        self.i2c.writeto_mem(self.addr, 0xF4, b'\x27') # Set oversampling for temperature, pressure, and normal mode
        # Configure the config register (0xF5)
        self.i2c.writeto_mem(self.addr, 0xF5, b'\xA0') # Set standby time to 1000 ms, filter coefficient to 16, and SPI mode to 0
        
        
    def read_calibration(self):
        cal_data = self.i2c.readfrom_mem(self.addr, 0x88, 24)
        self.dig_T1 = cal_data[1] << 8 | cal_data[0]
        self.dig_T2 = cal_data[3] << 8 | cal_data[2]
        self.dig_T3 = cal_data[5] << 8 | cal_data[4]
        self.dig_P1 = cal_data[7] << 8 | cal_data[6]
        self.dig_P2 = cal_data[9] << 8 | cal_data[8]
        self.dig_P3 = cal_data[11] << 8 | cal_data[10]
        self.dig_P4 = cal_data[13] << 8 | cal_data[12]
        self.dig_P5 = cal_data[15] << 8 | cal_data[14]
        self.dig_P6 = cal_data[17] << 8 | cal_data[16]
        self.dig_P7 = cal_data[19] << 8 | cal_data[18]
        self.dig_P8 = cal_data[21] << 8 | cal_data[20]
        self.dig_P9 = cal_data[23] << 8 | cal_data[22]
        
        
    def get_temperature(self):
        raw_data = self.i2c.readfrom_mem(self.addr, 0xfa, 3)
        adc_T = raw_data[0] << 16 | raw_data[1] << 8 | raw_data[2]
        adc_T >>= 4
        var1 = (((adc_T >> 3) - (self.dig_T1 << 1)) * self.dig_T2) >> 11
        var2 = (((((adc_T >> 4) - self.dig_T1) * ((adc_T >> 4) - self.dig_T1)) >> 12) * self.dig_T3) >> 14
        self.t_fine = var1 + var2
        temperature = (self.t_fine * 5 + 128) >> 8
        return temperature / 100
    

    def get_pressure(self):
        raw_data = self.i2c.readfrom_mem(self.addr, 0xf7, 3)
        adc_P = raw_data[0] << 16 | raw_data[1] << 2 | raw_data[2]
        adc_P >>= 4
        var1 = (self.t_fine >> 1) - 64000
        var2 = (((var1 >> 2) * (var1 >> 2)) >> 11) * self.dig_P6
        var2 = var2 + ((var1 * self.dig_P5) << 1)
        var2 = (var2 >> 2) + (self.dig_P4 << 16)
        var1 = (((self.dig_P3 * (((var1 >> 2) * (var1 >> 2)) >> 13)) >> 3) + ((self.dig_P2 * var1) >> 1)) >> 18
        var1 = ((32768 + var1) * self.dig_P1) >> 15
        pressure = 1048576 - adc_P
        pressure = ((pressure - (var2 >> 12)) * (3125))
        if var1 == 0:
            print("\n\n!!!! Divide by 0, return 0 !!!!\n\n")
            self.read_calibration()
            self.configure()
            return 0
        else:
            pressure = pressure // var1 * 2
            var1 = (self.dig_P9 * (((pressure >> 3) * (pressure >> 3)) >> 13)) >> 12
            var2 = ((pressure >> 2) * self.dig_P8) >> 13
            pressure = pressure + ((var1 + var2 + self.dig_P7) >> 4)
            return pressure
        
    def get_altitude(self, sea_level_pressure=101325):
        pressure = self.get_pressure()
        if pressure > 1:
            altitude = 44330 * (1 - ((pressure / sea_level_pressure) ** 0.1903))
            return altitude
        else:
            return 0
        

class CD74HC4067:
    def __init__(self, s0_pin, s1_pin, s2_pin, s3_pin, output_pin):
        self.s0 = Pin(s0_pin, Pin.OUT)
        self.s1 = Pin(s1_pin, Pin.OUT)
        self.s2 = Pin(s2_pin, Pin.OUT)
        self.s3 = Pin(s3_pin, Pin.OUT)
        self.output = Pin(output_pin, Pin.IN)
        utime.sleep_ms(50)

        if output_pin == 26:
            self.adc = ADC(0)
        elif output_pin == 27:
            self.adc = ADC(1)
        elif output_pin == 28:
            self.adc = ADC(2)
            

    def read_channel(self, data_Type, channel):
        self.s0.value(channel & 1)
        self.s1.value(channel & 2)
        self.s2.value(channel & 4)
        self.s3.value(channel & 8)
        RAW_Reading = self.adc.read_u16()
        voltage_ADC = RAW_Reading * 3.3 / 65535
        
        if data_Type == "RAW":
            return RAW_Reading
        elif data_Type == "VOLT" :
            return voltage_ADC
        


led_pin = Pin('LED', Pin.OUT)

#Init DHT22 Temperature and Humidity sensor
EN_DHT = Pin(0, Pin.OUT)
EN_DHT.value(1)
dht22 = dht.DHT22(Pin(1))

#TSL_2561 Setup
EN_TSL2561 = Pin(6, Pin.OUT)
EN_TSL2561.value(1)

i2c_TSL = I2C(1, sda = Pin(2), scl = Pin(3))
devices = i2c_TSL.scan()
print(devices)
sensor_TSL2561 = TSL2561(i2c_TSL)

#BMP280 Setup
EN_BMP280 = Pin(7, Pin.OUT)
EN_BMP280.value(1)

i2c = I2C(0, sda = Pin(8), scl = Pin(9))

# scan for devices
devices = i2c.scan()

# print the I2C addresses of the devices found
print("I2C ADDR: ", devices)
bmp = BMP280(i2c)

#MQ_Sensors Setup:
EN_MQ1 = Pin(13, mode = Pin.OUT)
EN_MQ2 = Pin(12, mode = Pin.OUT)
EN_MQ3 = Pin(11, mode = Pin.OUT)
EN_MQ4 = Pin(10, mode = Pin.OUT)
EN_MQ5 = Pin(14, mode = Pin.OUT)
EN_MQ6 = Pin(15, mode = Pin.OUT)

EN_MQ1.value(0)
EN_MQ2.value(0)
EN_MQ3.value(0)
EN_MQ4.value(0)
EN_MQ5.value(0)
EN_MQ6.value(0)

MQ1_DIG_VAL = 0
MQ2_DIG_VAL = 0
MQ3_DIG_VAL = 0
MQ4_DIG_VAL = 0
MQ5_DIG_VAL = 0
MQ6_DIG_VAL = 0

MQ1_ANLG_VAL = 0
MQ2_ANLG_VAL = 0
MQ3_ANLG_VAL = 0
MQ4_ANLG_VAL = 0
MQ5_ANLG_VAL = 0
MQ6_ANLG_VAL = 0

EN_MUX = Pin(28, mode = Pin.OUT)
EN_MUX.value(1)

MUX = CD74HC4067(21, 20, 19, 18, 27)
delay = 25
prev_start_stop = "Y"
start_stop = "N"
DEF_ENV_DATA = {
            "G1": 999,
            "G2": 999,
            "G3": 999,
            "G4": 999,
            "G5": 999,
            "G6": 999,
            "G7": 999,
            "G8": 999,
            "G9": 999,
            "GA": 999,
            "GB": 999,
            "GC": 999,
            "BT" : 999,
            "BP" : 999,
            "BA" : 999,
            "LX" : 999,
            "T": 999,
            "H": 999
            }
prev_ENV_DATA = None
while True:
    ch = sys.stdin.readline()
    if ch is not None:
        data_in = json.loads(ch)
        speed_mot = data_in["S"]
        dir_mot = data_in["D"]
        start_stop = data_in["X"]
        
    led_pin.toggle()
    
    if start_stop == "Y":
        if prev_start_stop == "N":
            EN_DHT.value(1)
            dht22 = dht.DHT22(Pin(1))
            EN_TSL2561.value(1)
            sensor_TSL2561 = TSL2561(i2c_TSL)
            EN_BMP280.value(1)
            bmp = BMP280(i2c)
            EN_MUX.value(1)
            prev_start_stop = "Y"

        TSL_LUX = sensor_TSL2561.read_lux()
        #Read BMP280 Sensor
        BMP_TEMP = bmp.get_temperature()
        BMP_BAR = bmp.get_pressure()/100_000
        BMP_ALT =  bmp.get_altitude()

        EN_MQ1.value(1)
        utime.sleep_ms(delay)
        MQ1_ANLG_VAL = MUX.read_channel("VOLT", 0)
        MQ1_DIG_VAL = MUX.read_channel("VOLT", 1)
        EN_MQ1.value(0)
        utime.sleep_ms(delay)
        
        
        EN_MQ2.value(1)
        utime.sleep_ms(delay)
        MQ2_ANLG_VAL = MUX.read_channel("VOLT", 0)
        MQ2_DIG_VAL = MUX.read_channel("VOLT", 1)
        EN_MQ2.value(0)
        utime.sleep_ms(delay)

        EN_MQ3.value(1)
        utime.sleep_ms(delay)
        MQ3_ANLG_VAL = MUX.read_channel("VOLT", 0)
        MQ3_DIG_VAL = MUX.read_channel("VOLT", 1)
        EN_MQ3.value(0)
        utime.sleep_ms(delay)

        EN_MQ4.value(1)
        utime.sleep_ms(delay)
        MQ4_ANLG_VAL = MUX.read_channel("VOLT", 0)
        MQ4_DIG_VAL = MUX.read_channel("VOLT", 1)
        EN_MQ4.value(0)
        utime.sleep_ms(delay)

        EN_MQ5.value(1)
        utime.sleep_ms(delay)
        MQ5_ANLG_VAL = MUX.read_channel("VOLT", 0)
        MQ5_DIG_VAL = MUX.read_channel("VOLT", 1)
        EN_MQ5.value(0)
        utime.sleep_ms(delay)

        EN_MQ6.value(1)
        utime.sleep_ms(delay)
        MQ6_ANLG_VAL = MUX.read_channel("VOLT", 0)
        MQ6_DIG_VAL = MUX.read_channel("VOLT", 1)
        EN_MQ6.value(0)
        utime.sleep_ms(delay)
        
        try:
            EN_DHT.value(1) # Enable DHT22 Sensor
            #utime.sleep_ms(100)
            # Take a reading from the DHT22
            dht22.measure()

            # Print the temperature and humidity readings
            # print("Distance1: {:.2f} cm".format(distance1), "MQ ANALOG Volt: ", MQ_AN_VAL, "MQ DIGITAL Volt: ", MQ_DIG_VAL, "Temperature: {} C".format(dht22.temperature()),"Humidity: {} %".format(dht22.humidity()))
            
            # solutia 1
            # print("{" + f"\"distance\": \"{distance1:.2f}\", \"mq_analog_volt\": \"{MQ_AN_VAL}\", \"mq_digital_volt\": \"{MQ_DIG_VAL}\", \"temperature\": \"{dht22.temperature()}\", \"humidity\": \"{dht22.humidity()}\"" + "}")
            
            # solutia 2
            ENV_DATA = {
                "G1": round(MQ1_ANLG_VAL, 2),
                "G2": round(MQ2_ANLG_VAL, 2),
                "G3": round(MQ3_ANLG_VAL, 2),
                "G4": round(MQ4_ANLG_VAL, 2),
                "G5": round(MQ5_ANLG_VAL, 2),
                "G6": round(MQ6_ANLG_VAL, 2),
                "G7": round(MQ1_DIG_VAL, 2),
                "G8": round(MQ2_DIG_VAL, 2),
                "G9": round(MQ3_DIG_VAL, 2),
                "GA": round(MQ4_DIG_VAL, 2),
                "GB": round(MQ5_DIG_VAL, 2),
                "GC": round(MQ6_DIG_VAL, 2),
                "BT" : round(BMP_TEMP, 2),
                "BP" : round(BMP_BAR, 2),
                "BA" : round(BMP_ALT, 2),
                "LX" : round(TSL_LUX, 2),
                "T": dht22.temperature(),
                "H": dht22.humidity()
            }
            print(json.dumps(ENV_DATA))
            prev_ENV_DATA = ENV_DATA
            
        except OSError as e:
            # print("Distance1: {:.2f} cm".format(distance1), "MQ ANALOG Volt: ", MQ_AN_VAL, "MQ DIGITAL Volt: ", MQ_DIG_VAL,"Failed to read from DHT22: ", e)
                
            # solutia 1
            # print("{" + f"\"distance\": \"{distance1:.2f}\", \"mq_analog_volt\": \"{MQ_AN_VAL}\", \"mq_digital_volt\": \"{MQ_DIG_VAL}\", \"dht_error\": \"{e}\" " + "}")
        
            # solutia 2

            ENV_DATA = {
                "G1": round(MQ1_ANLG_VAL, 2),
                "G2": round(MQ2_ANLG_VAL, 2),
                "G3": round(MQ3_ANLG_VAL, 2),
                "G4": round(MQ4_ANLG_VAL, 2),
                "G5": round(MQ5_ANLG_VAL, 2),
                "G6": round(MQ6_ANLG_VAL, 2),
                "G7": round(MQ1_DIG_VAL, 2),
                "G8": round(MQ2_DIG_VAL, 2),
                "G9": round(MQ3_DIG_VAL, 2),
                "GA": round(MQ4_DIG_VAL, 2),
                "GB": round(MQ5_DIG_VAL, 2),
                "GC": round(MQ6_DIG_VAL, 2),
                "BT" : round(BMP_TEMP, 2),
                "BP" : round(BMP_BAR, 2),
                "BA" : round(BMP_ALT, 2),
                "LX" : round(TSL_LUX, 2),
                "ER": e
            }
            prev_ENV_DATA = ENV_DATA
            print(json.dumps(ENV_DATA))
        # Read the value from the potentiometer
        #utime.sleep(0.5)
        # Convert the potentiometer value to a speed value between 0 and 1
        #speed = pot_value / 655

        #print(speed)

        # Wait for a short amount of time before reading the potentiometer again
    else:
        if prev_start_stop == "Y":
            EN_DHT.value(0)
            EN_TSL2561.value(0)
            EN_BMP280.value(0)
            EN_MUX.value(0)
            prev_start_stop = "N"
            if prev_ENV_DATA is None:
                print(json.dumps(DEF_ENV_DATA))
            else:
                print(json.dumps(prev_ENV_DATA))

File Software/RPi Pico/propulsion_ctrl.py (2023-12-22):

#This code is used for IMU Sensor and Motor Control MicroController
#AKA pico_motoare
import select
import sys
import utime
from machine import Pin, I2C, PWM, ADC
import json
import struct

# MPU6500 I2C address
#MPU6500_I2C_ADDR = 0x69 #AD0 connected to VCC
MPU6500_I2C_ADDR = 0x68 #AD0 connected to GND

# MPU6500 register addresses
MPU6500_ACCEL_XOUT_H = 0x3B
MPU6500_GYRO_XOUT_H = 0x43
MPU6500_PWR_MGMT_1 = 0x6B
MPU6500_WHO_AM_I = 0x75

class MPU6500:
    def __init__(self, i2c):
        self.i2c = i2c
        self.i2c_addr = MPU6500_I2C_ADDR
        utime.sleep_ms(500)
        self.power_on()

    def power_on(self):
        # Wake up the MPU6500 from sleep mode
        self.i2c.writeto_mem(self.i2c_addr, MPU6500_PWR_MGMT_1, b'\x00')
        utime.sleep_ms(500)

    def who_am_i(self):
        # Read the WHO_AM_I register to verify the MPU6500's identity
        data = self.i2c.readfrom_mem(self.i2c_addr, MPU6500_WHO_AM_I, 1)
        return data[0]

    def read_acceleration(self):
        # Read the accelerometer data registers
        data = self.i2c.readfrom_mem(self.i2c_addr, MPU6500_ACCEL_XOUT_H, 6)

        # Convert the raw data to signed 16-bit integers
        x = struct.unpack('>h', data[0:2])[0]
        y = struct.unpack('>h', data[2:4])[0]
        z = struct.unpack('>h', data[4:6])[0]

        # Scale the acceleration values to m/s^2
        scale_factor = 9.80665 / 16384.0
        x = x * scale_factor
        y = y * scale_factor
        z = z * scale_factor

        return (x, y, z)

    def read_gyroscope(self):
        # Read the gyroscope data registers
        data = self.i2c.readfrom_mem(self.i2c_addr, MPU6500_GYRO_XOUT_H, 6)

        # Convert the raw data to signed 16-bit integers
        x = struct.unpack('>h', data[0:2])[0]
        y = struct.unpack('>h', data[2:4])[0]
        z = struct.unpack('>h', data[4:6])[0]

        # Scale the gyroscope values to degrees/s
        scale_factor = 1 / 131.0
        x = x * scale_factor
        y = y * scale_factor
        z = z * scale_factor

        return (x, y, z)

class A4990:
    def __init__(self, pwm_pin, dir_pin):
        self.pwm_pin = Pin(pwm_pin, Pin.OUT)
        self.dir_pin = Pin(dir_pin, Pin.OUT)
        self.pwm = PWM(self.pwm_pin)
        self.pwm.freq(10_000)

    def set_speed(self, speed):
        if speed < 0:
            speed = 0
        elif speed > 1:
            speed = 1
        self.pwm.duty_u16(int(speed * 65535))

    def stop(self):
        self.set_speed(1)
        self.dir_pin.value(0)

    def forward(self, speed):
        self.dir_pin.value(0)
        self.set_speed(speed)

    def backward(self, speed):
        self.dir_pin.value(1)
        self.set_speed(1-speed)

class Robot:
    def __init__(self):
        self.motor1 = A4990(pwm_pin=0, dir_pin=2)  # Front left motor
        self.motor2 = A4990(pwm_pin=4, dir_pin=6)  # Front right motor
        self.motor3 = A4990(pwm_pin=8, dir_pin=10)  # Back left motor
        self.motor4 = A4990(pwm_pin=12, dir_pin=14)  # Back right motor

    def go_left(self, speed):
        self.motor1.backward(speed)
        self.motor2.backward(speed)
        self.motor3.forward(speed)
        self.motor4.forward(speed)

    def go_right(self, speed):
        self.motor1.forward(speed)
        self.motor2.forward(speed)
        self.motor3.backward(speed)
        self.motor4.backward(speed)

    def go_forward(self, speed):
        self.motor1.forward(speed)
        self.motor2.backward(speed)
        self.motor3.backward(speed)
        self.motor4.forward(speed)

    def go_backward(self, speed):
        self.motor1.backward(speed)
        self.motor2.forward(speed)
        self.motor3.forward(speed)
        self.motor4.backward(speed)

    def rotate_left(self, speed):
        self.motor1.backward(speed)
        self.motor2.backward(speed)
        self.motor3.backward(speed)
        self.motor4.backward(speed)

    def rotate_right(self, speed):
        self.motor1.forward(speed)
        self.motor2.forward(speed)
        self.motor3.forward(speed)
        self.motor4.forward(speed)

    def stop(self):
        self.motor1.stop()
        self.motor2.stop()
        self.motor3.stop()
        self.motor4.stop()


led_pin = Pin('LED', Pin.OUT)

robot = Robot()
sensor_temp = ADC(4)
# Define ADC object for reading the potentiometer
adc = ADC(28)

#Enable Motor Drives
EN_DRV1 = Pin(21, mode=Pin.OUT)
EN_DRV1.value(1)

EN_DRV2 = Pin(20, mode=Pin.OUT)
EN_DRV2.value(1)

robot.stop()

#Example code:
EN_MPU6500 = Pin(22, Pin.OUT) #VCC?
EN_MPU6500.value(1)

i2c_MPU = I2C(1, sda = Pin(18), scl = Pin(19))

devices = i2c_MPU.scan()
print(devices)
utime.sleep_ms(2000)
imu_MPU6500 = MPU6500(i2c_MPU)

speed_mot = 0.75
prev_start_stop = "Y"
while True:
    # try to acquire lock - wait if in use
    ch = sys.stdin.readline()
    if ch is not None:
        data_in = json.loads(ch)
        speed_mot = data_in["S"]
        dir_mot = data_in["D"]
        start_stop = data_in["X"]
        
    led_pin.toggle()


    # Control the speed of each Motor using the A4990 class
    if start_stop == "Y":
        if prev_start_stop == "N":
            EN_DRV1.value(1)
            EN_DRV2.value(1)
            EN_MPU6500.value(1)
            imu_MPU6500 = MPU6500(i2c_MPU)
            prev_start_stop = "Y"
        
        if dir_mot == "F":
            robot.go_forward(speed_mot)
            utime.sleep_ms(10)
        elif dir_mot == "B":
            robot.go_backward(speed_mot)
            utime.sleep_ms(10)
        elif dir_mot == "L":
            robot.go_left(speed_mot)
            utime.sleep_ms(10)
        elif dir_mot == "R":
            robot.go_right(speed_mot)
            utime.sleep_ms(10)
        elif dir_mot == "RL":
            robot.rotate_left(speed_mot)
            utime.sleep_ms(10)
        elif dir_mot == "RR":
            robot.rotate_right(speed_mot)
            utime.sleep_ms(10)
        else:
            robot.stop()
            utime.sleep_ms(10)

        accel_x, accel_y, accel_z = imu_MPU6500.read_acceleration()
        gyro_x, gyro_y, gyro_z = imu_MPU6500.read_gyroscope()

        DATA_MOTS = {
            "AX": round(accel_x, 2),
            "AY": round(accel_y, 2), 
            "AZ": round(accel_z, 2), 
            "GX": round(gyro_x, 2), 
            "GY": round(gyro_y, 2),
            "GZ": round(gyro_z, 2), 
            "X": dir_mot
        }
        print(json.dumps(DATA_MOTS))
    else:
        if prev_start_stop == "Y":
            robot.stop()
            EN_DRV1.value(0)
            EN_DRV2.value(0)
            EN_MPU6500.value(0)
            DATA_MOTS = {
                "AX": 999,
                "AY": 999, 
                "AZ": 999, 
                "GX": 999, 
                "GY": 999,
                "GZ": 999, 
                "X": start_stop
            }
            prev_start_stop = "N"
            print(json.dumps(DATA_MOTS))

    # Wait for a short amount of time before reading the potentiometer again
    utime.sleep_ms(50)
